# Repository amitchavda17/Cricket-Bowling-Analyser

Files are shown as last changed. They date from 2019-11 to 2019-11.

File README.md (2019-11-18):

# Cricket-Bowling-Analyser

Cricket Bolwing analyser is  a low cost embedded system  that can be used for analysing bolwers perfromance analysis in Cricket.The system is capable of measuring line length and speed of delivery.
The system consist of an  sensor matrix integrated with embedded system for measuring line and length of delivery and uses ultrasonic sensor for measuring the speed of dleivery.
A basic GUI is designed for  providing performance  analysis to user.

## The [Report](https://github.com/amitchavda17/Cricket-Bowling-Analyser/blob/master/Report.pdf) file contians following
* Detail explanation of project with required components and  results  
* Process of designing sensor matrix using velostat with measurments 
* Block diagram for system 
* Schematic Diagram for [PCB](https://github.com/amitchavda17/Cricket-Bowling-Analyser/tree/master/Circuit)
* Circuit diagram for sesnor arduino interfacing

## Code files
* [sensor interfacing](https://github.com/amitchavda17/Cricket-Bowling-Analyser/blob/master/sensor_matrix.ino) this file contains code for data acqusition from sensor matrix and generating results
* [Speed measrument](https://github.com/amitchavda17/Cricket-Bowling-Analyser/blob/master/speed_measurment.ino) code for speed measrument using ultrasonic sensor
* [Live visualization](https://github.com/amitchavda17/Cricket-Bowling-Analyser/blob/master/live_visualization.pde) Processing3 code written in java for visualzing results in real time
* [GUI](https://github.com/amitchavda17/Cricket-Bowling-Analyser/tree/master/GUI) using pyQt in python and webased using html

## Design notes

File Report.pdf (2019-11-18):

# CRICKET BOWLING ANALYSER

I

## ABSTRACT

This project is an alternative for the expensive performance evaluating systems available

in the market today. Individual bowlers will be able to evaluate their performances on their own

with the help of statistics and graphs provided by our system. More specifically, individuals will

be able to keep a check on their consistency as a bowler based on bowling parameters like line,

length, and speed.

In this system, we will be developing a grid of velostat polymer which will be used as a

sensor for the detection of location of ball’s impact on the pitch. This will help us to provide the

line and length of the delivery.

The data collected from this sensor will be accumulated which can be later used to present

to the user using Data Visualization techniques which will make this data intelligible for the user.

The final aim of this project is to provide a performance analyzing and evaluating system

which can be utilized by any layman for the betterment of the sport

II

## TABLE OF CONTENTS

Sr. No. | Page Title | Page No.
1. | Introduction | 1
| 1.1 Introduction of project | 1
| 1.2 Aim and Objective | 4
| 1.3 Scope of the project | 5
2. | Literature Survey | 6
| 2.1 Currently Available Technology | 6
| 2.2 Study Of Sensor | 7
| 2.3 Market Research | 11
3. | Problem Statement | 12
4. | System Development | 13
| 4.1 Block Diagram | 13
| 4.2 Circuit Diagram | 14
| 4.3 PCB Design | 15
| 4.4 Explanation | 16
| 4.5 Working | 16
5. | Hardware Details | 20
| 5.1 Hardware Requirements | 20
6. | Software Details | 24
| 6.1 Software Requirements | 24

III

Sr. No. | Page Title | Page No.
7. | Cost Of Materials | 30
| 7.1 Costing Details | 30
8. | Code Flow Chart | 30
9. | Results | 33
10. | Conclusion & Future Scope | 38
11. | References | 39
12. | Annexure | 40

IV

## LIST OF FIGURES

Fig. no. | Figure | Page no.
1.1 | Cricket pitch | 1
1.2 | Pitch Dimensions | 2
1.3 | Length of Delivery | 3
2.1 | Hawk Eye | 6
2.2 | Pitch Vision | 6
2.3 | Piezoelectric sensor | 7
2.4 | Force sensing resistor | 8
2.5 | Ultrasonic sensor | 9
2.6 | Infrared sensor | 9
2.7 | Velostat | 10
2.8 | Feedback | 11
4.1 | Block Diagram | 13
4.2 | Circuit Diagram | 14
4.3 | Speed Circuit | 14
4.4 | PCB Schematic | 15
4.5 | PCB | 15
4.6 | Implemented Sensor | 17
4.7 | Ultrasonic waves | 18
5.1 | Arduino Nano | 21
5.2 | Arduino Mega | 22
5.3 | Velostat | 22
5.4 | Mux 506 | 23
5.5 | Ultrasonic senor | 23
6.1 | Processing3 | 24
6.2 | Processing 3 display | 25
6.3 | Led and Arduino Interfacing | 26
6.4 | Python | 28

V

Fig. no. | Figure Title | Page no.
9.1 | System Connection | 33
9.2 | Processing3 Visualization | 34
9.3 | CSV file | 35
9.4 | GUI home page | 36
9.5 | GUI second page | 36
9.6 | Line Graph | 37
9.7 | Length Graph | 37

VI

## LIST OF TABLES

Table no. | Content of table | Page no.
2.1 | Technology Comparison | 7
4.1 | Sensor Mat Dimensions | 16
5.1 | Component Specifications | 20
7.1 | Cost of Materials | 30

## CHAPTER 1

## 1. INTRODUCTION

## 1.1 Introduction of project

Cricket is a bat and ball game played between two teams, 11 players each, on a field

which has a rectangular 22-yard-long pitch in the centre. The basic purpose of the game is to

score more runs than your opposing team.

A Cricket match is divided into periods called innings. During the innings, one team

bats while the other fields and vice-versa. All 11 players on the fielding team are on the pitch

at the same time however only two batsmen are the field at any one time.

Cricket fields tend to be oval in shape. The end which is marked off is called the

boundary, with the rectangle “pitch” in the center.

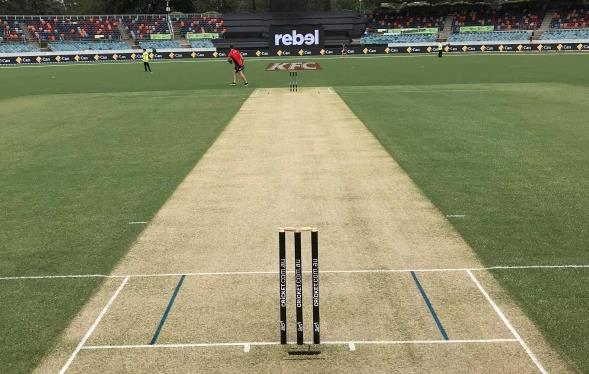
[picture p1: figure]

Fig 1.1 Cricket Pitch

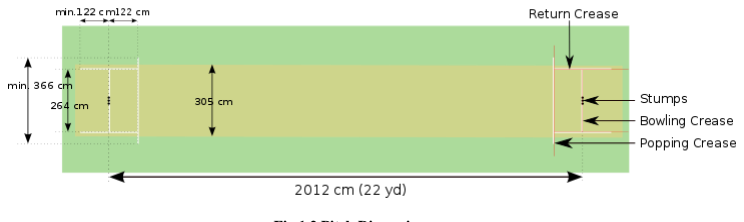
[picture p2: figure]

Fig 1.2 Pitch Dimensions

The essence of the sport is that a bowler delivers (i.e., bowls) the ball from his end of

the pitch towards the batsman who, armed with a bat is "on strike" at the other end.

Bowling, in cricket, is the action of propelling the ball toward the wicket defended by

a batsman. A player skilled at bowling is called a bowler. A single act of bowling the ball

towards the batsman is called a ball or a delivery

The bowler's job is to take as many wickets as possible. That job will be a lot easier if

they have control of their line and length, making the batsman's job of scoring runs that much

more difficult. The line is the direction of the ball in accordance with the batsman's stumps,

while the length is the area of the pitch where the ball bounces.

The length of the ball will determine whether the batsman will play on the front or back foot.

There are five areas the bowler can aim for:

Short length (8 or more meters in front of stumps)

Good length (6 to 8 meters in front of stumps)

Full length (2 to 6 meters in front of stumps)

Yorker(0 to 2 meters in front of stumps)

Different lines that the ball may be said to be traveling on maybe towards off stump,

middle stump or leg stump, outside leg stump, or outside off stump.Line controls how much

room the batsman has to play various shots, and sometimes dictates what shot he must play.

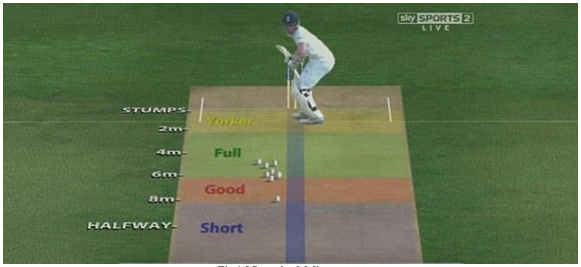
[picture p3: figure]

Fig 1.3 Length of delivery

In the past, cricketers could not see their performance parameters like bowling length, speed

and line; and batting parameters too. If a cricketer was not performing in a match or was lacking

in specific parameter,the fault could not be figured , Like is the bowler injured, less stamina or

learning is wrong, that is bad muscle memory.

With the fast-paced improvement in technology nowadays it is integrated with sports.

Even in cricket there are major changes due to this, like the hawk eye system, sensor bat, led

stumps and stump microphone and camera. In this modern time where we are inclined towards

perfection, we need to work on smart systems that can help sportspeople improve their

gameplay that’s easy for them and are less time consuming.

This Project “Cricket bowling analyser” is a reliable sytem that takes over the task of

evaluating parameters of bowlers in the cricket very accurately and notifies about the

parameters and fault delivery in the bowlers bowling via graphical and statistical data. This

system will consist of VELOSTAT-based pressure mat which will be fabricated in a grid like

structure and laid on the cricket pitch, for speed it will be radar gun. When the bowler’s balls,

the ball will fall on a square part of grid which will give the perfect spot on pitch and once it

hits stump mat, the deviation from the original landing spot and final spot will give the line.

This system can also be enhanced by providing video processing through cameras which

can be recorded and viewed later on. The cricket bowling analyser is a simple sytem that can

turn out to be very helpful for the kids as well as adults who want to learn bowling without

external assistance or in absence of coach

## 1.2 Aim and Objective of project

1. To provide a technology driven aid in the field of cricket that can help budding

cricketers to enhance their performance.

2. Tracking statistics of players with a modern digital approach.
3. Provide a low cost easy to use alternative

## 1.3 Scope of the Project

1. To provide a technologically driven aid that will help in monitoring bowling

performance by measuring line, length and speed of a delivery.

2. A low-cost system that will give necessary features of high cost professional system

that are not easily affordable.

3. This Application will help a weaker section of society to portray their skills.
4. The main target audience of this project are school academies and small clubs

(gymkhanas).

5. This can also be used by individual to target a particular spot to improve bowling and

analyse himself.

## CHAPTER 2

## 2. Literature Survey

## 2.1 Currently available Technology:

### 2.1.1 Hawk eye:

Hawk-Eye is a computer system used in numerous sports such as cricket, tennis,

Gaelic football and volleyball, to visually track the trajectory of the ball and display a

profile of its statistically most likely path as a moving image

Cost- 1.2 crores INR

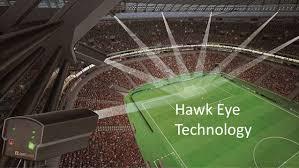
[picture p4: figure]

Fig2.1 Hawk Eye

### 2.1.2 Pitch Vision:

Pitch vision is an innovative cricket training platform that facilitates an analytical

system consisting of motion tracking and video analysis

Cost- 3 -10 Lakhs INR

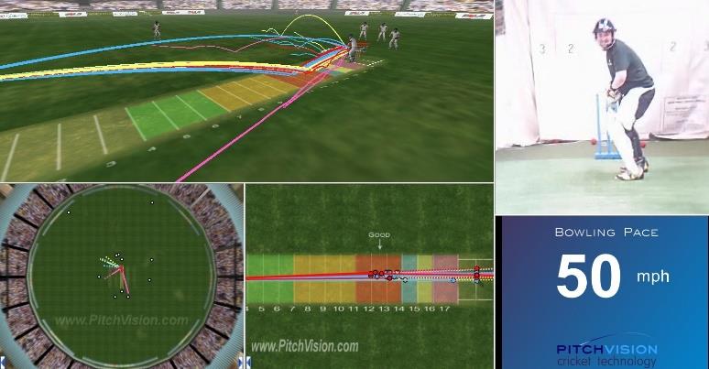
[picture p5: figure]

Fig 2.2 Pitch Vision

Table 2.1 Technology Comparison

The currently available systems considered for cricket, work on the principle of

Image processing and require expensive hardware, and very high processing power and

storage. Hence, we have designed a less expensive embedded system which requires less

processing power and storage.

The main requirement of the embedded system is to collect data on line, length and speed for this purpose we have studied various sensors which can be used to perform the desired task.

## 2.2 Study of Sensor:

### 2.2.1 Piezoelectric sensor:

A piezoelectric sensor is a device that uses the piezoelectric effect, (https://en.wikipedia.org/wiki/Piezoelectric_effect) to measure changes

in pressure, (https://en.wikipedia.org/wiki/Pressure) acceleration, (https://en.wikipedia.org/wiki/Acceleration) temperature, (https://en.wikipedia.org/wiki/Temperature) strain, (https://en.wikipedia.org/wiki/Strain_(materials_science)) or force (https://en.wikipedia.org/wiki/Force) by converting them to an electrical

charge. (https://en.wikipedia.org/wiki/Electrical_charge) Piezoelectric sensors are versatile tools for the measurement of various processes. They

are used for quality assurance, (https://en.wikipedia.org/wiki/Quality_assurance) process control, (https://en.wikipedia.org/wiki/Process_control) for research and development in many

industries.

SYSTEM | TECHNOLOGY | HARDWARE | APPLICATION | COST (INR)
HAWK EYE | IMAGE PROCESSING | HIGH END CAMERA | MATCH | 2.5CR
PITCH VISION | EMBEDDED SYSTEM & IMAGE PROCESSING | CAMERA, SENSOR MAT | MATCH & TRAINING | 3LAKHS
CRICKET BOWLING ANALYZER | EMBEDDED SYSTEM | SENSOR MAT | TRAINING | 30K

Usability-Piezoelectric sensor are inexpensive pressure sensors but the output of these

sensor is not stable so they are not suited for measurement of line and length of delivery as they

fail to detect impact of ball and also they are easily prone to damage by high impact.

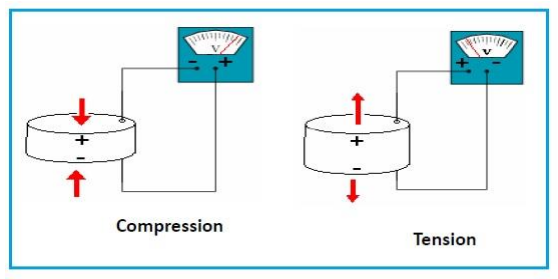
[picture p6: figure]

Fig 2.3 piezoelectric sensor

### 2.2.2 Force sensing resistor:

Force-sensing resistors consist of a conductive polymer, (https://en.wikipedia.org/wiki/Conductive_polymer) which changes resistance in a

predictable manner following application of force to its surface. They are normally supplied as

a polymer sheet or that can be applied by screen-printing. (https://en.wikipedia.org/wiki/Screen_printing) The sensing film consists of both

electrically conducting and non-conducting particles suspended in matrix. The particles are

sub-micrometer sizes, and are formulated to reduce the temperature dependence, improve

mechanical properties and increase surface durability.

Usability-These are expensive sensors which are excellent for detection of impact but

it is practically difficult and expensive to design a pressure sensing grid using these sensors.

Fig2.4 Force sensing resistor

### 2.2.3 Ultra sonic sensor:

Ultrasonic sensors are a type of acoustic sensor divided into three broad categories:

transmitters, receivers and transceivers. Transmitters convert electrical signals (https://en.wikipedia.org/wiki/Signal_(electrical_engineering)) into ultrasound, (https://en.wikipedia.org/wiki/Ultrasound)

receivers convert ultrasound into electrical signals, and transceivers can both transmit and

receive ultrasound.

Usability- Work on ultrasound and have a field of 120 degree so they are used for

measurement of speed of delivery

Fig 2.5 Ultrasonic sensor

### 2.2.4 IR sensor:

An infrared sensor is an electronic device that emits in order to sense some aspects of

the surroundings. An IR sensor can measure the heat of an object as well as detects the motion.

These types of sensors measures only infrared radiation, rather than emitting it that is called as

a passive IR sensor.

Usability-Due to low range of operation they are not advisable for use.

Fig 2.6 IR sensor

### 2.2.5 Velostat

Velostat is a piezoresistive material, meaning it’s electrical resistance decreases when

pressured. When sandwiched between two conductive layers, it has a wonderful range for

making pressure and bend sensors. It can also be used for resistive sensing over distance,

position sensing. Velostat is a back, opaque, volume-conductive, carbon-impregnated

polyolefin. The electrical characteristics are not affected by age or humidity (but they do

change when melted under the iron).

Usability-This is well suited for design of pressure sensor as per the requirement of the

project. This polymer is soft, flexible, light, thin and can handle heavy impacts.

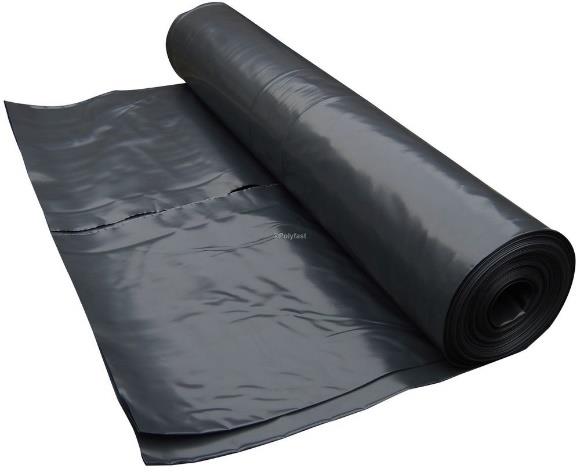
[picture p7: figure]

Fig 2.7 Velostat polymer

## 2.3 Market Research:

During the process of system designing we met with a few cricket clubs and explained

them our system idea to get their feedback and suggestion on practical application of the

proposed system.

We visited PTVA Sports Acadmey,Vile Parle,Mumbai to get a feedback on our

idea .We met with their head coach Mr.Suren D.Ayre

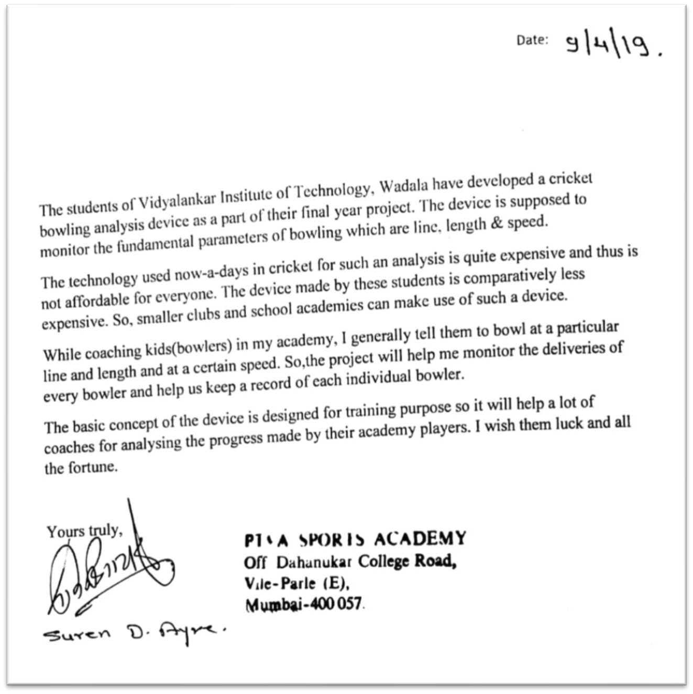
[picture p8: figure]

Fig 2.8 Feedback

## CHAPTER 3

## 3. Problem Statement

To provide a cheaper alternative for the expensive systems available for cricket

bowling performance analysis and help individual bowlers to evaluate their own consistency

and progress.

## CHAPTER 4

## 4. System Development

## 4.1 Block Diagram

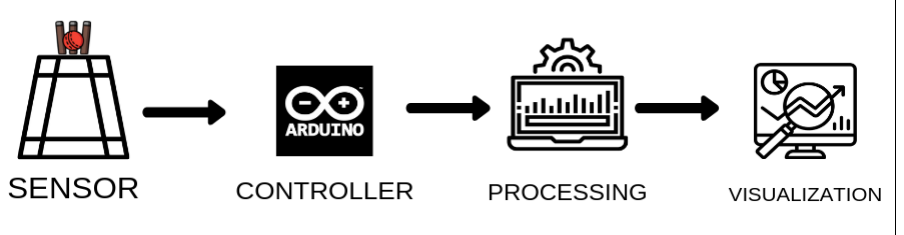
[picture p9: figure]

Fig 4.1 Block Diagram

The main goal of the system is to monitor and analyze cricket bowling parameters

viz. line, length and speed which are the essential parameters of the multi-faceted sport for any

budding cricketer. This will help the player to access and improve upon his/her bowling

engendering higher performances. Due to this system, the fundamentals of any cricket bowler

will be tested and polished.

An embedded system is designed that uses pressure sensors developed using velostat

to detect the location of ball impact, which is then interfaced with the controller, and the

acquired data is processed appropriately and is used to give proper information about the line,

length, and length of the delivery.

This processed data will be stored in the storage device and specific directory will

be maintained for every user for all the overs bowled and this data can be processed using data

visualization techniques and can be represented in the form of graphs and chart which provide

a summary of the performance and help in better understanding the data instead of mere table

or spread sheets. Data can be stored for a longer duration which will help in tracking a

performance for a period which gives all the insights in the various trends that has taken place

during this period.

## 4.2 Circuit Diagram:

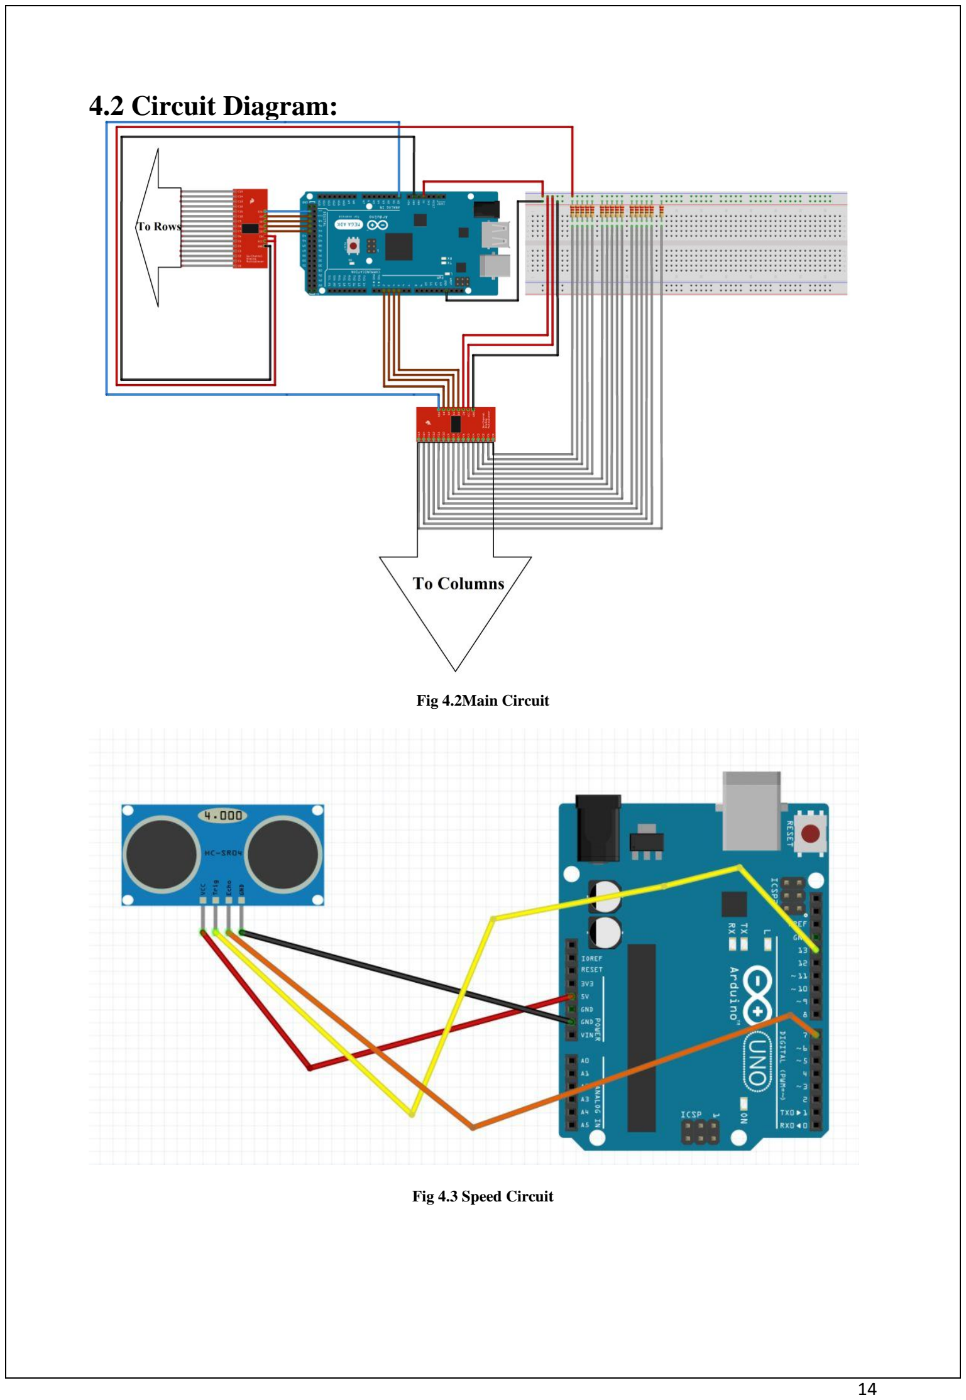
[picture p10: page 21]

Fig 4.2Main Circuit

Fig 4.3 Speed Circuit

## 4.3 PCB

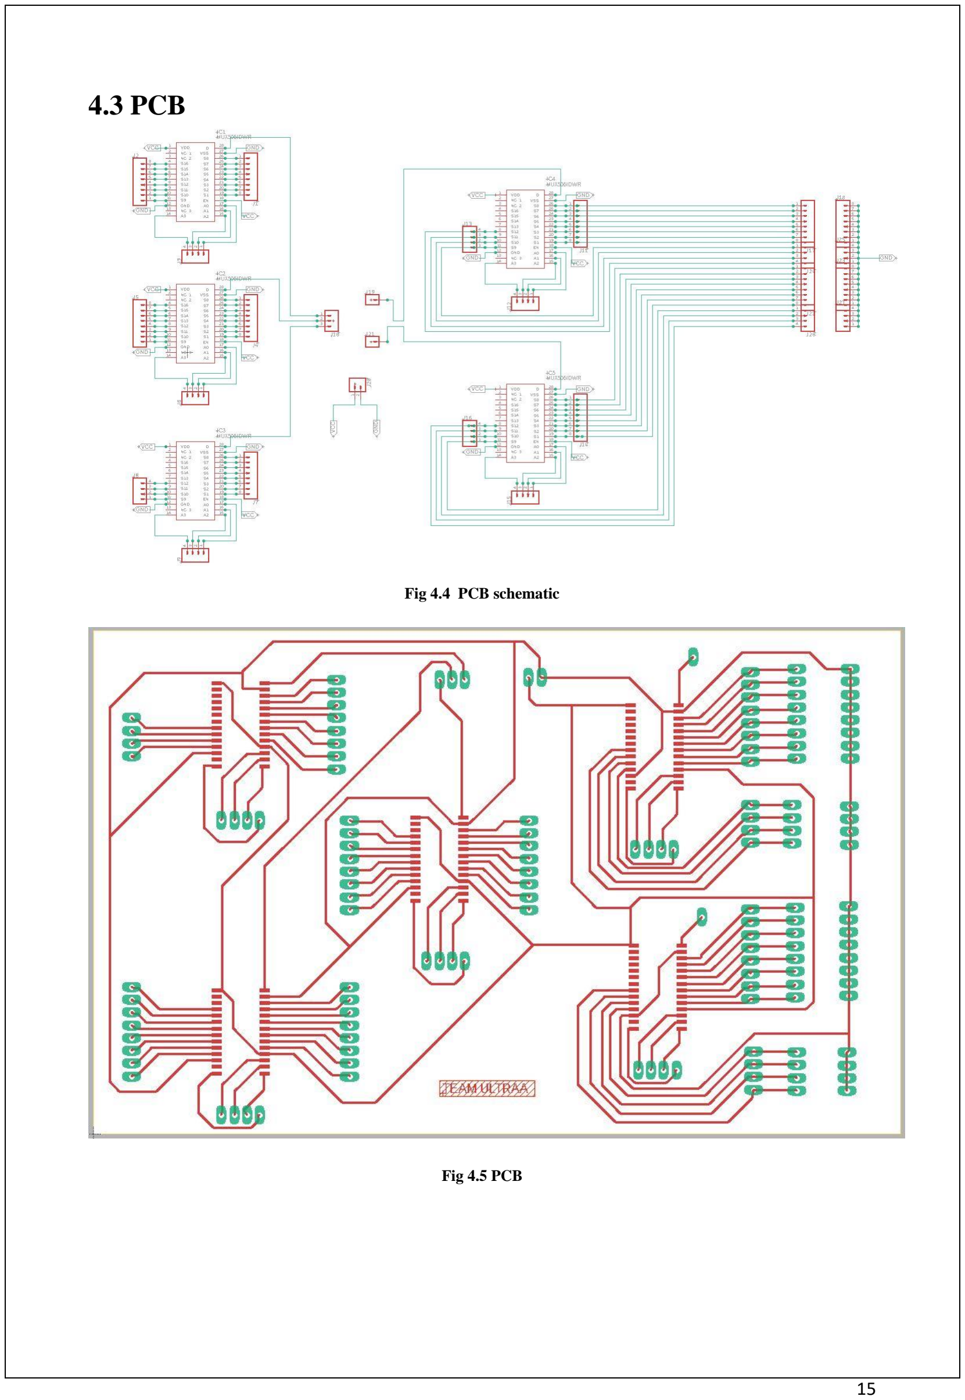
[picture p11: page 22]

Fig 4.4 PCB schematic

Fig 4.5 PCB

## 4.4 Explanation:

The circuit is designed for measuring line and length of ball delivery, it consists of 2

pair of 16:1 mux interfaced with Arduino. One pair of mux is interfaced with Pitch pressure

sensing matrix for measuring length of delivery and another pair is connected with back screen

matrix for measuring line of delivery.

The 16 channels of 1 mux are connected to rows of matrix and the 16 channels of other

mux are connected to columns of same matrix. Select pins of multiplexers are connected to

Arduino, switching of multiplexer channels is done via Arduino.

A voltage divider section is created on the output side and the output of this section is

fed to 16 channels of second mux then this Output is given to analog pin of Arduino.

An ultrasonic sensor is interfaced with Arduino for measuring the speed of delivery and

the speed data is also fed to csv file.

## 4.5 Working:

The primary task of the system is to measure line, length, speed of delivery. For

measurement different sensors are interfaced with microcontroller to acquire the data.

### 4.5.1 Pressure sensing mat:

BIG MAT
COPPER STRIP | | LENGTH (cm) | BREADTH (cm) | NO OF STRIPS
| ROW | 75 | 3.5 | 30
| COLUMN | 180 | 3.5 | 12
VELOSTAT | LENGTH (cm) | BREADTH (cm)
| 180 | 75

SMALL MAT
COPPER STRIP | | LENGTH (cm) | BREADTH (cm) | NO OF STRIPS
| ROW | 75 | 3.5 | 12
| COLUMN | 75 | 3.5 | 12
VELOSTAT | LENGTH (cm) | BREADTH (cm)
| 75 | 75

Table 4.1 Senor mat dimensions

Pressure sensing mat is designed using velostat polymer. The aim of this sensor is to

give the exact location at which pressure is applied. Matrix structure of the mat is helpful in

finding the location of pressure change. The sensor will return 2D coordinates of the location

of pressure change. A number of copper strips are used as rows and columns and the velostat

polymer is sandwiched between the copper strips to create the pressure sensing matrix. The

mat used in the system consists of a matrix structure with 30 rows and 12 columns. The data

given by this matrix is used to track the length of delivery. Another matrix of 12 rows and 9

columns is used to measure the line of the delivery. The 30 rows X 12 columns mat used for

determining the length of the delivery is placed on the pitch and the 12 rows X 9 columns mat

is placed behind the stumps on a vertically oriented screen, which helps in determining the line

of delivery.

The matrix structure is interfaced with the microcontroller using analog multiplexer

mux506. The multiplexers are used to control the input and output of the matrix. The rows and

columns of the matrix are connected to the channels of separate set of multiplexers responsible

for controlling rows and columns independently. The row section of the matrix is used as input

and the columns are used to measure the output.

The operation of pressure sensing matrix is dependent on change in impedance of the

polymer, according to the ohm’s law voltage is directly proportional to impedance, using this

law the voltage change at the location of ball’s impact is monitored using the mux.

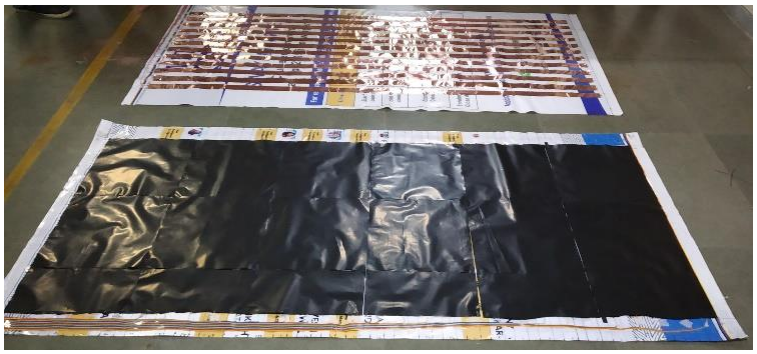
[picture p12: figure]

Fig 4.6 Implemented Sensor

The microcontroller sends a 5V input signal to the multiplexers,which are controls, the

switching of rows. The signal is transferred to one channel at a time and the columns are

continuously monitored for detecting any major surge in voltage. This voltage surge from the

multiplexers is fed into the microcontroller.

The system takes approximately 64 ms to scan both the mats with Arduino Mega 2560 (16

MHz crystals). After removing the pre-scaler, the scanning time is reduced to 11 ms. This

helps us to detect the impact of the ball.

### 4.5.2 Ultrasonic speed gun:

The speed gun is used for measuring the speed of delivery and it is designed using

ultrasonic sensor. Ultrasonic sensors measure distance by using ultrasonic waves. The sensor

head emits an ultrasonic wave and receives the wave reflected back from the target. Ultrasonic

Sensors measure the distance to the target by measuring the time between the emission and

reception.

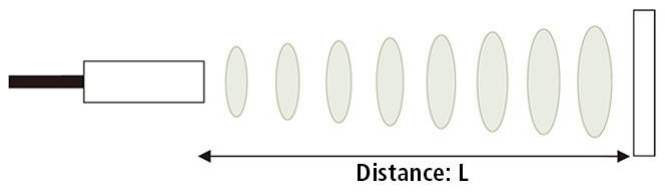
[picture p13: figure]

Fig 4.7 ultrasonic waves

An ultrasonic sensor uses a single ultrasonic element for both emission and reception.

In a reflective model ultrasonic sensor, a single oscillator emits and receives ultrasonic waves

alternately. This enables miniaturization of the sensor head.

Ultrasonic sensor module comprises of one transmitter and one receiver. The

transmitter can deliver 40 KHz ultrasonic sound while the maximum receiver is designed to

accept only 40 KHz sound waves. The receiver ultrasonic sensor that is kept next to the

transmitter shall thus be able to receive reflected 40 KHz, once the module faces any obstacle

in front. Thus, whenever any obstacles come ahead of the ultrasonic module it calculates the

time taken from sending the signals to receiving them since time and distance are related for

sound waves passing through air medium at 343.2m/sec.

### Distance calculation:

The distance can be calculated with the following formula:

Distance L = 1/2 × T × C

where L is the distance, T is the time between the emission and reception, and C is the sonic

speed. (The value is multiplied by 1/2 because T is the time for go-and-return distance.)

### Speed measurement:

The ultrasonic sensor is placed on the stumps facing towards the bowler. The sensor

continuously emits ultrasound, when the ball is bowled the sensor detects the ball twice, one at

distance d1 and one more time at distance d2. So, only two waves reflected back at the distances

d1 and d2 are considered. This enables us to determine the time between the two distances and

hence the speed of the delivery.

### 4.5.3 Data Acquisition and Visualization:

The data collected from sensor matrix is fed to Arduino where processing of the data

takes places. Further, the processed data is then sent serially to Processing 3 software which is

used to format the data and load in CSV file. At the same time the formatted data is visualized

in real time. CSV files are used to store the data on line, length and speed of delivery. This

accumulated data is used for long-term analysis of trends in performance. The data from CSV

files is loaded in python and analyzed using graphs to show the tabular data in simple form.

Finally, a GUI is developed to give user a smooth access to this data.

## CHAPTER 5

## 5. HARDWARE DETAILS

## 5.1Hardware Requirments:

SR NO | COMPONENTS | SPECIFICATION
1 | Arduino Nano | ATmega328P,16MHz
2 | Arduino Mega | ATmega 2560 AU
3 | Velostat polymer | 50,000 ohm/sq metre
4 | MUX 506 | 16:1 Analog Mux
5 | Ultrasonic Sensor | Detection range: 2cm – 1000cm
6 | Copper Stripes | Conductivity: 5.96 x 10⁷ S/m

Table 5.1: Component Specifications
5.1.1Arduino Nano:

Arduino Nano is an open source platform for programming. The Arduino Nano is a

small, complete, and breadboard-friendly board based on the Atmega328P.It has 22

digital input/output pins (of which 6 can be used as PWM outputs), 8 analog inputs, a 16 MHz

ceramic resonator, a USB connection, an ICSP header, and automatic reset.

It contains everything needed to support the microcontroller; simply connect it to a

computer with a USB cable or power it with a AC-to-DC adapter or battery to get started. The

Arduino Nano has many facilities for communicating with a computer, another

Arduino, or other microcontrollers. The Atmega328P provide UART TTL (5V) serial

communication, which is available on digital pins 0 (RX) and 1 (TX). The Arduino

Nano can be programmed with the Arduino software (download). (http://www.arduino.org/software) The Atmega328P

on the Arduino Nano comes preburnt with a boot loader that allows you to upload

new code to it without the use of an external hardware programmer.

Fig 5.1 Arduino Nano

### 5.1.2 Arduino Mega:

Arduino is an open-source physical computing platform based on a simple i/o board

and a development environment that implements the Processing/Wiring language. Arduino can

be used to develop stand-alone interactive objects or can be connected to software on your

computer (e.g. Flash, Processing, MaxMSP). The open-source IDE can be downloaded for free

(currently for Mac OS X, Windows, and Linux).

The Arduino Mega is a microcontroller board based on the ATmega2560. It has 54

digital input/output pins (of which 14 can be used as PWM outputs), 16 analog inputs, 4 UARTs

(hardware serial ports), a 16 MHz crystal oscillator, a USB connection, a power jack, an ICSP

header, and a reset button. It contains everything needed to support the microcontroller; simply

connect it to a computer with a USB cable or power it with a AC-to-DC adapter or battery to

get started. Never fear for accidental electrical discharge, either since since the Mega also

includes a plastic base plate to protect it!

The Mega 2560 R3 also adds SDA and SCL pins next to the AREF. In addition, there

are two new pins placed near the RESET pin. One is the IOREF that allow the shields to adapt

to the voltage provided from the board. The other is a not connected and is reserved for future

purposes. The Mega 2560 R3 works with all existing shields but can adapt to new shields which

use these additional pins.

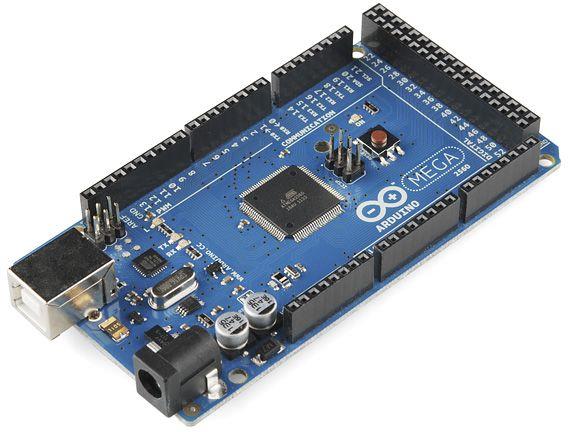
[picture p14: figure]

Fig 5.2 Arduino Mega

### 5.1.3 Velostat Polymer:

Velostat (50000-ohm, 4 mil), which is produced by 3M and consists of a polymeric foil

(11µm thickness) impregnated with carbon black. For the electrodes, we use a copper sheet

strip (40 microns), which is also commonly available. The outer protection layer is made of a

plastic flex.

Due to its properties of changing its resistance with either flexing or pressure it is

becoming popular with hobbyists for making inexpensive sensors for microcontroller

experiments. One example of this is to make shoes which light up when the wearer takes a step.

Since the resistance (https://en.wikipedia.org/wiki/Electrical_resistance) in the circuit is reduced when pressure is applied, this reading can indicate

when weight is applied or removed from the shoes.

Fig 5.3 Velostat

### 5.1.4 Texas Instrument Mux506:

The MUX506 and MUX507 (MUX50x) are modern complementary metal-oxide

semiconductor (CMOS) precision analog multiplexers (muxes). The MUX506 offers 16:1

single-ended channels, whereas the MUX507 offers differential 8:1 or dual 8:1 single-ended

channels. The MUX506 and MUX507 work equally well with either dual supplies (±5 V to

±18 V) or a single supply (10 V to 36 V). These devices also perform well with symmetric

supplies (such as VDD = 12 V, VSS = –12 V), and unsymmetric supplies (such as VDD = 12

V, VSS = –5 V). All digital inputs have transistor-transistor logic (TTL) compatible thresholds,

providing both TTL and CMOS logic compatibility when operating in the valid supply voltage

range.

Fig 5.4 Mux506

### 5.1.6 Ultrasonic Sesnor:

Ultrasonic sensor module comprises of one transmitter and one receiver. The

transmitter can deliver 40 KHz ultrasonic sound while the maximum receiver is designed to

accept only 40 KHz sound waves. The receiver ultrasonic sensor that is kept next to the

transmitter shall thus be able to receive reflected 40 KHz, once the module faces any obstacle

in front. Thus, whenever any obstacles come ahead of the ultrasonic module it calculates the

time taken from sending the signals to receiving them since time and distance are related for

sound waves passing through air medium at 343.2m/sec.

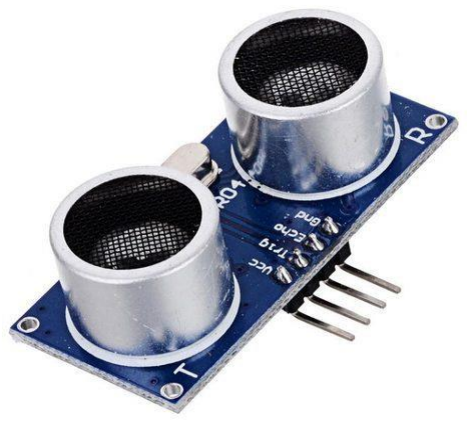
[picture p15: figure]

Fig 5.5 Ultrasonic Sensor

## CHAPTER 6

## 6. SOFTWARE DETAILS

## 6.1 Software Requirements:

### 6.1.1 Processing3:

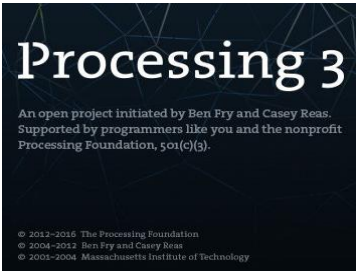
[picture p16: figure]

Fig 6.1 Processing 3

Processing is an open-source graphical library and integrated development environment

(IDE) / playground built for the electronic arts, new media art, and visual design communities

with the purpose of teaching non-programmers the fundamentals of computer programming in

a visual context.

Processing uses the Java language, with additional simplifications such as additional

classes and aliased mathematical functions and operations. As well as this, it also has a

graphical user interface for simplifying the compilation and execution stage.

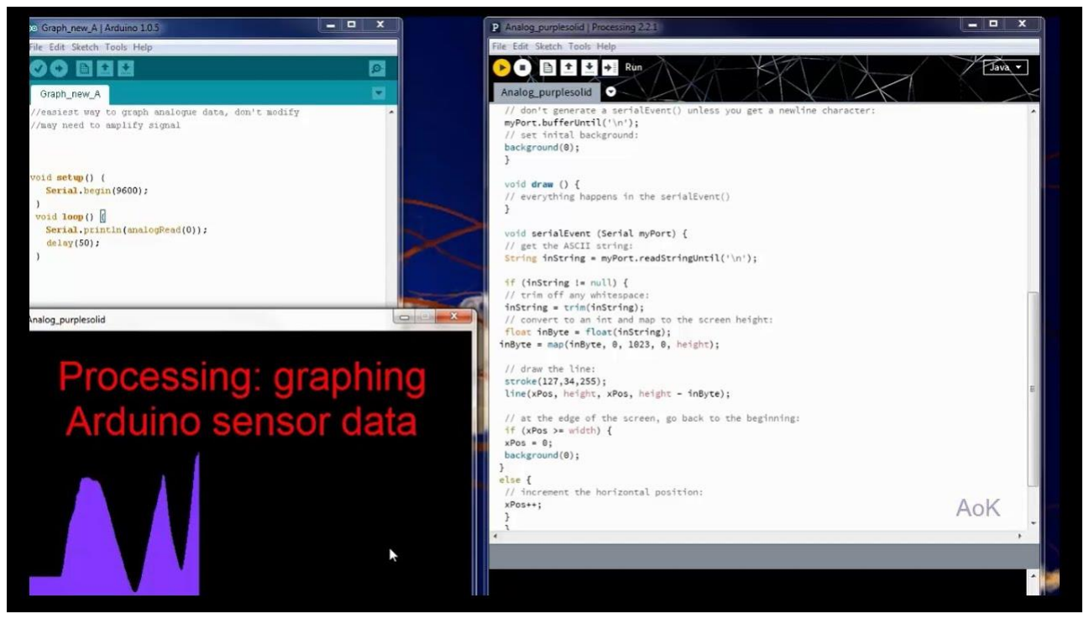
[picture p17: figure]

Fig 6.2 Processing 3 display

Interfacing Arduino with Processing3 using a simple example of turning a LED ON & OFF

Arduino Circuit

The connections for this tutorial are very easy. Connect the two end pins of the 1k

potentiometer to the 5V and the GND pin of the Arduino. Then connect the middle pin of the

potentiometer to the A0 on Arduino. Then connect the positive pin of the LED to pin 7 on the

Arduino and the negative pin of the LED to the GND pin through the 220 ohm resistor.

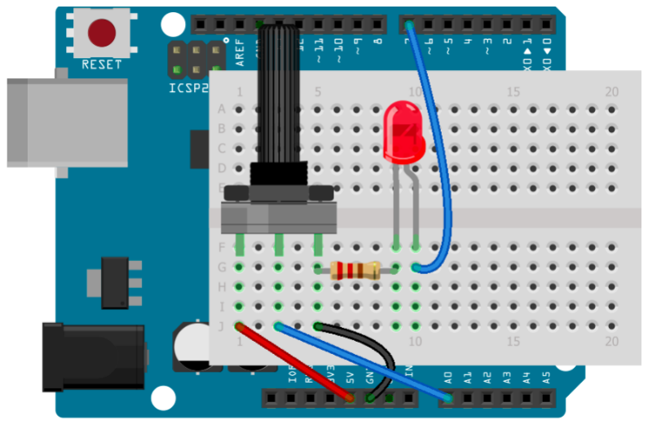
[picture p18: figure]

Fig 6.3 Led Arduino interfacing

Working

The Arduino IDE and the Processing IDE will communicate with each other through

serial communication. The Processing IDE has a serial library which makes it easy to

communicate with the Arduino.

When we move the potentiometer knob, the Arduino will send a value between 0 and

255 to the Processing IDE. The Processing IDE will then change the color of the serial window

according to the movement of the potentiometer knob.

Similarly, when we press the mouse button in the serial window of the Processing IDE,

the Processing IDE will send a ‘1’ or ‘0’ depending on the left or right mouse button to the

Arduino IDE. The Arduino IDE will then turn the LED ON or OFF according to the button

pressed.

Arduino Code

int led_pin = 7; // Initializing the LED pin
int pot_pin = A0; // Initializing the Potentiometer pin
int pot_output; // Declaring a variable for potentiometer output
void setup ( ) {
pinMode(led_pin, OUTPUT); // Declaring the LED pin as output pin Serial.begin(9600); // Starting the serial communication at 9600 baud rate }
void loop ( ) {
pot_output = analogRead (pot_pin); // Reading from the potentiometer
int mapped_output = map (pot_output, 0, 1023, 0, 255); // Mapping the output of potentiometer to 0-255 to be read by the Processing IDE
Serial.println (mapped_output); // Sending the output to Processing IDE

if (Serial.available ( ) > 0) { // Checking if the Processing IDE has send a value or not char state = Serial.read ( ); // Reading the data received and saving in the state variable
if(state == '1') | // If received data is '1', then turn on LED\
{
digitalWrite (led_pin, HIGH);
}
if (state == '0') { // If received data is '0', then turn off led digitalWrite (led_pin, LOW);
}
}
delay(50);
}

Processing

The Processing IDE will accept the data from the Arduino IDE through the Serial

communication and will change the color of the serial window according to the data. It will

also send ‘1’ or ‘0’ depending on the mouse button pressed. The Processing IDE has a serial

library which makes it able to communicate with the Arduino IDE.

import processing.serial.*; // Importing the serial library to communicate with the Arduino Serial myPort; // Initializing a vairable named 'myPort' for serial communication
float background_color ; // Variable for changing the background color
void setup ( ) {
size (500, 500); // Size of the serial window, you can increase or decrease as you want
myPort = new Serial (this, "COM3", 9600); // Set the com port and the baud rate according to the Arduino IDE
myPort.bufferUntil ( '\n' ); // Receiving the data from the Arduino IDE
}
void serialEvent (Serial myPort) {
background_color = float (myPort.readStringUntil ( '\n' ) ) ; // Changing the background color according to received data
}
void draw ( ) {

background ( 150, 50, background_color ); // Initial background color, when we will open the serial window

if ( mousePressed && ( mouseButton == LEFT ) ) { // if the left mouse button is pressed

myPort.write ( '1' ) ; // send a '1' to the Arduino IDE

}

if ( mousePressed && ( mouseButton == RIGHT ) ) { // if the right mouse button is pressed

myPort.write ( '0' ) ; // Send a '0' to the Arduino IDE

### 6.1.2 Python 3:

Python is an interpreted, (https://en.wikipedia.org/wiki/Interpreted_language) high-level, (https://en.wikipedia.org/wiki/High-level_programming_language) general-purpose (https://en.wikipedia.org/wiki/General-purpose_programming_language) programming language. (https://en.wikipedia.org/wiki/Programming_language) Created

by Guido van Rossum (https://en.wikipedia.org/wiki/Guido_van_Rossum) and first released in 1991, Python has a design philosophy that

emphasizes code readability, (https://en.wikipedia.org/wiki/Code_readability) notably using significant whitespace. (https://en.wikipedia.org/wiki/Significant_whitespace) It provides constructs that

enable clear programming on both small and large scales.

Python is dynamically typed (https://en.wikipedia.org/wiki/Dynamic_programming_language) and garbage-collected. (https://en.wikipedia.org/wiki/Garbage_collection_(computer_science)) It supports multiple programming

paradigms, (https://en.wikipedia.org/wiki/Programming_paradigm) including procedural, (https://en.wikipedia.org/wiki/Procedural_programming) object-oriented, (https://en.wikipedia.org/wiki/Object-oriented_programming) and functional programming. (https://en.wikipedia.org/wiki/Functional_programming) Python

features a comprehensive standard library, (https://en.wikipedia.org/wiki/Standard_library) and is referred to as "batteries included".

Python interpreters are available for many operating systems. (https://en.wikipedia.org/wiki/Operating_system) CPython, (https://en.wikipedia.org/wiki/CPython) the reference

implementation (https://en.wikipedia.org/wiki/Reference_implementation) of Python, is open-source software (https://en.wikipedia.org/wiki/Open-source_software) and has a community-based development

model. Python and CPython are managed by the non-profit Python Software Foundation. (https://en.wikipedia.org/wiki/Python_Software_Foundation)

### 6.4 Python

### 6.1.3 PyQt:

PyQt is one of the most popular Python bindings for the Qt cross-platform C++

framework. PyQt developed by Riverbank Computing Limited. Qt itself is developed as part

of the Qt Project. PyQt provides bindings for Qt 4 and Qt 5. PyQt is distributed under a choice

of licences: GPL version 3 or a commercial license.

PyQt is available in two editions: PyQt4 which will build against Qt 4.x and 5.x and

PyQt5 which will only build against 5.x. Both editions can be built for Python 2 and 3. PyQt contains over 620 classes that cover graphical user interfaces, XML handling, network

communication, SQL databases, Web browsing and other technologies available in Qt.

The latest iteration of PyQt is v5.11.3. It fully supports Qt 5.11.2.

PyQt4 runs on Windows, Linux, Mac OS X and various UNIX platforms. PyQt5 also

runs on Android and iOS.

### 6.1.4 Matplotlib:

Matplotlib is a Python 2D plotting library which produces publication quality figures

in a variety of hard copy formats and interactive environments across platforms. Matplotlib can

be used in Python scripts, the Python and IPython shells, the Jupyter notebook, web application

servers, and four graphical user interface toolkits.

Matplotlib tries to make easy things easy and hard things possible. You can generate

plots, histograms, power spectra, bar charts, error charts, scatterplots, etc., with just a few lines

of code. For examples, see the sample plots and thumbnail gallery.

For simple plotting the pyplot module provides a MATLAB-like interface, particularly

when combined with IPython. For the power user, you have full control of line styles, font

properties, axes properties, etc, via an object-oriented interface or via a set of functions familiar

to MATLAB users.

## CHAPTER 7

## 7. Cost of Materials

## 7.1 Costing Details:

Sr no | Name | Quantity | Cost(INR)
1 | Velostat | 1.8 sq.meter | 11000
2 | Arduino Mega | 1 | 800
3 | Mux506 | 4 | 400
4 | Aruino Nano | 1 | 500
5 | PCB | 1 | 1000
6 | Ultrasonic sensor | 1 | 100
8 | Copper sheet | 30 sq feet | 1800
9 Wires ,cables and | accessories | | 6000
Total | | | 21,500

Table 7.1 Cost of Materials

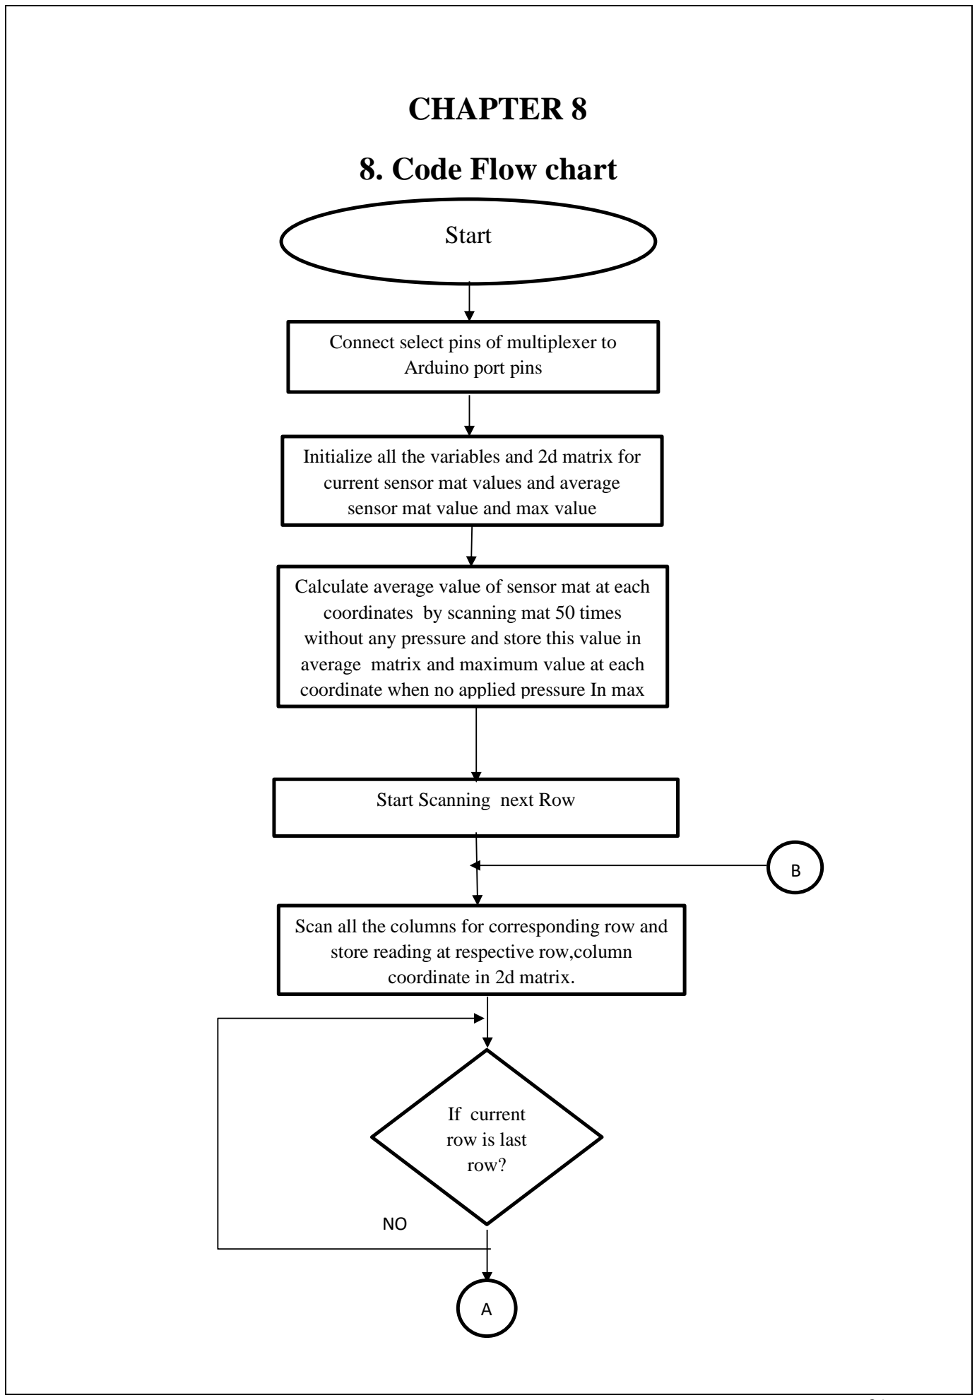
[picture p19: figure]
CHAPTER 8; 8. Code Flow chart; Start; Connect select pins of multiplexer to Arduino port pins; current sensor mat values and average sensor mat value and max value; coordinates by scanning mat 50 times; Start Scanning next Row; store reading at respective row,column coordinate in 2d matrix.; If current row is last row?

Initialize all the variables and 2d matrix for

Calculate average value of sensor mat at each

without any pressure and store this value in average matrix and maximum value at each coordinate when no applied pressure In max

Scan all the columns for corresponding row and

Using the current matrix reading stored in 2D mat matrix and average stored in avg matrix

coordinate and return the coordinate with

Repeat the same process for back screen matrix

## CHAPTER 9 9. Results

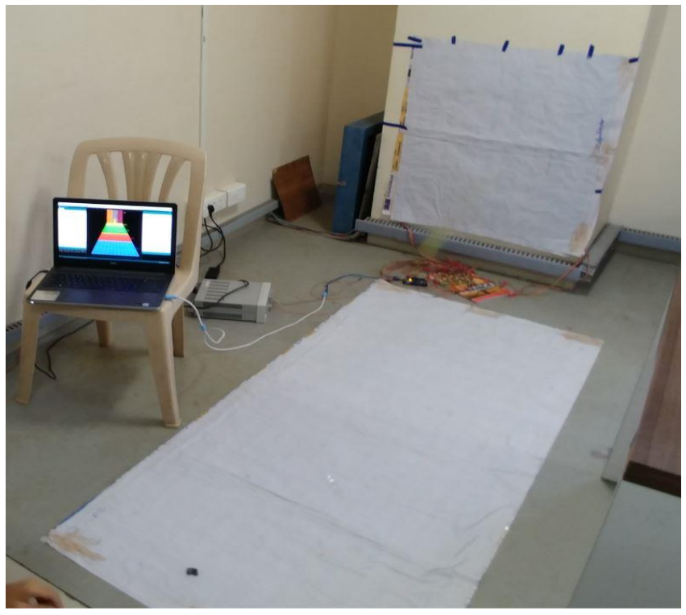
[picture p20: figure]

Fig 9.1 System Connection

This is how the setup looks like when the whole system is assembled. The larger mat is

overlaid on the ground (which gives the length) and the smaller mat is held behind (which gives

the line).

On an average the ball takes approximately 11 ms to bounce off the pitch. Our system

can detect whether the ball has bounced on the pitch if the bounce time in 11 ms. That is, the

arduino scans the enter mat (both mats) in 11 ms.

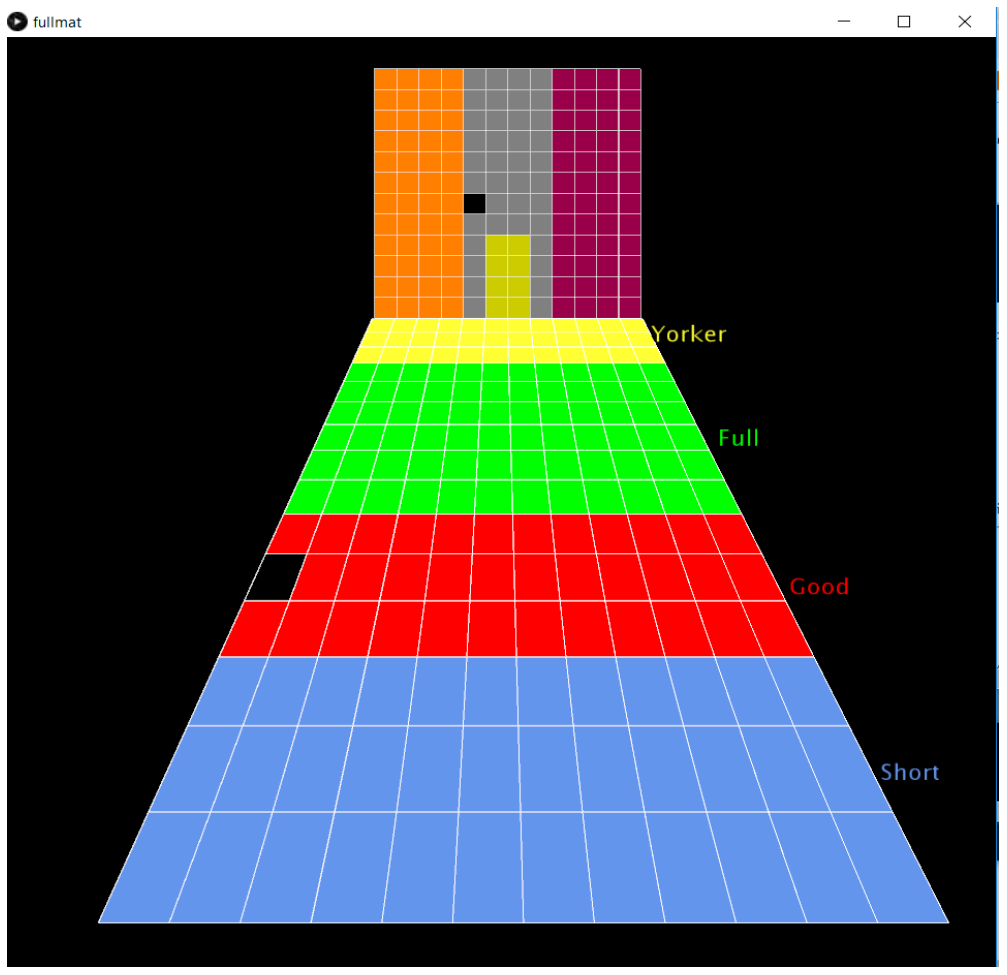
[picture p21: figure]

Fig 9.2 Processing3 visualization

This is virtual representation of the real setup developed using processing3.It shows

live visualization of the real time delivery.The bottom pitch is divided into 4 section which

shows the length of delivery viz. Yorker,full,good,short.The back screen is divided into 3

section which shows line of delivery viz. off,middle,leg.

The black box visible on the screen shows the exact coordinates of the delivery and the

colour code helps in deciphering the length and line of delivery.processing3 also collects the

data from Arduino and loads the data into csv file.

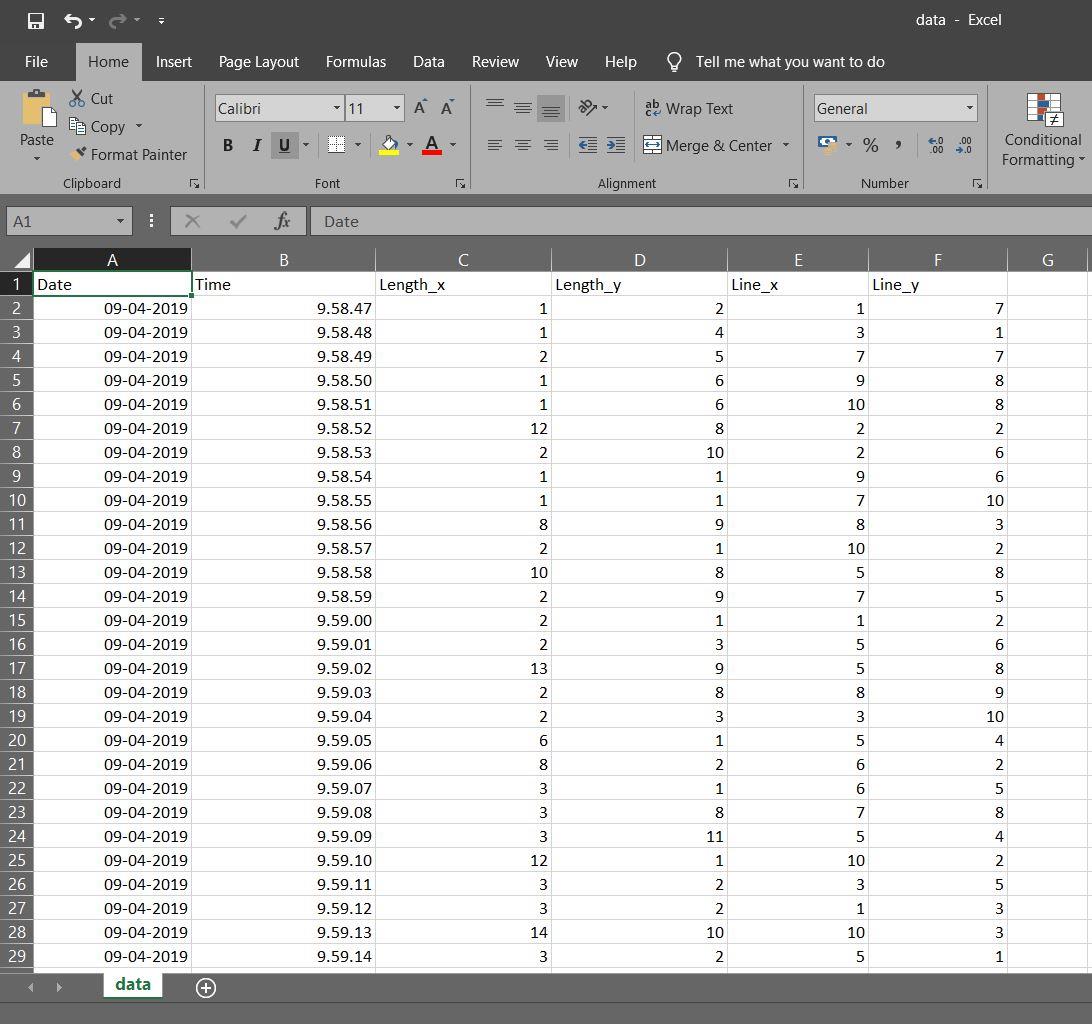
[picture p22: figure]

Fig 9.3 CSV File

The above figure shows the format in which data is stored in csv files. The line and

length data from the processing software is stored along with date and time instantaneously,

when it was acquired. This csv file helps in long term storage of data and this data can be

retrieved later for further graphical analysis.length_x and length_y represents the x,y

coordinate of lengthparticular delivery similarly line_x and line_y gives the x,y coordinate for

line. Date-time stamp is added for aiding the processing of data for generating graphs.

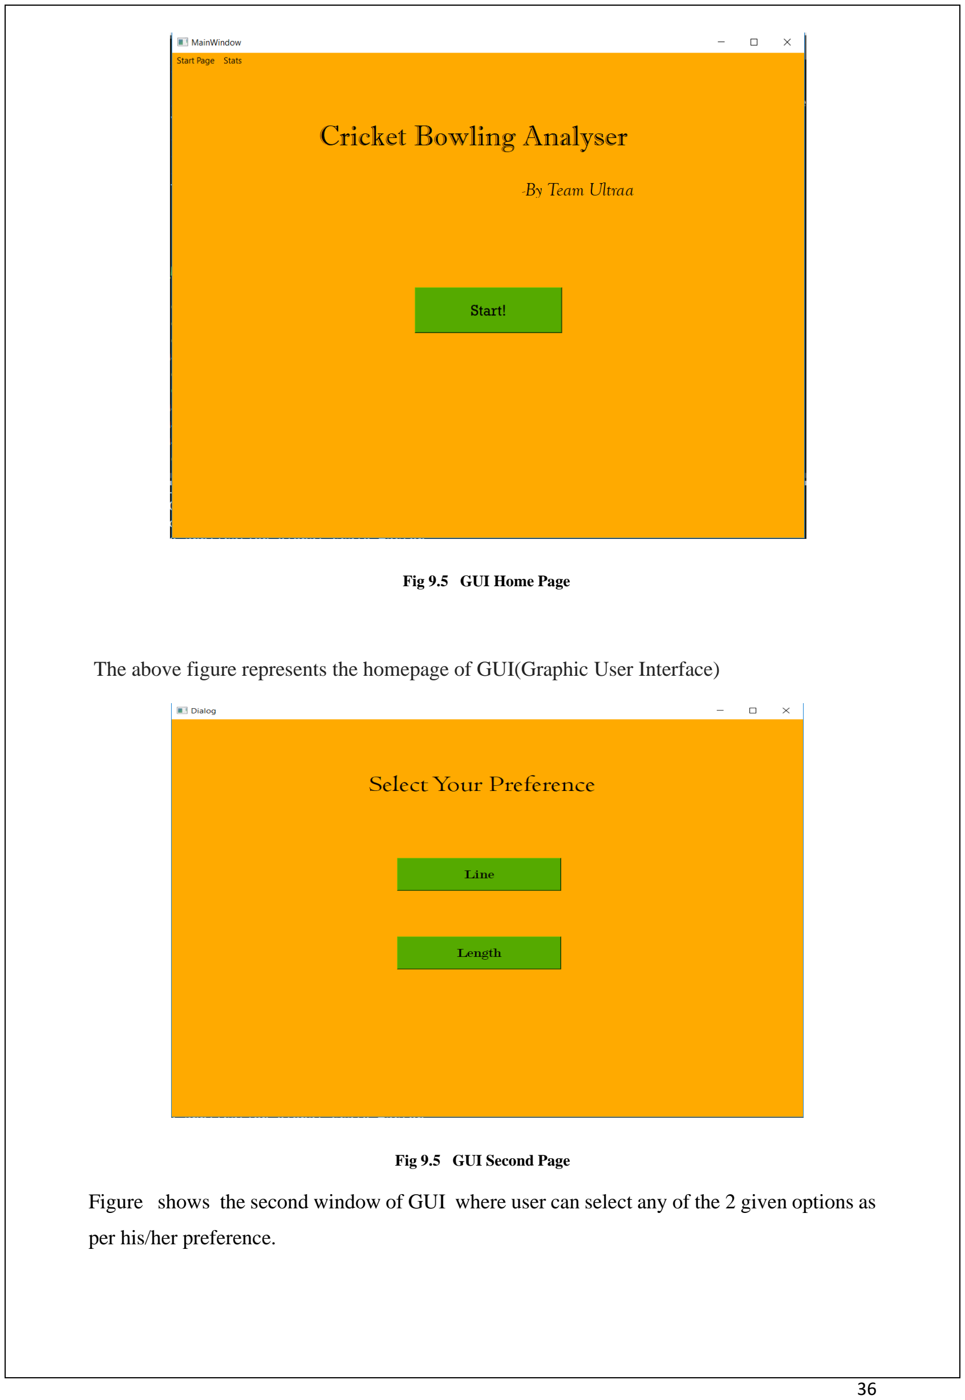
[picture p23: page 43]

Fig 9.4 GUI Home page

Fig 9.5 GUI Home Page

The above figure represents the homepage of GUI(Graphic User Interface)

Fig 9.5 GUI Second Page

Figure shows the second window of GUI where user can select any of the 2 given options as

per his/her preference.

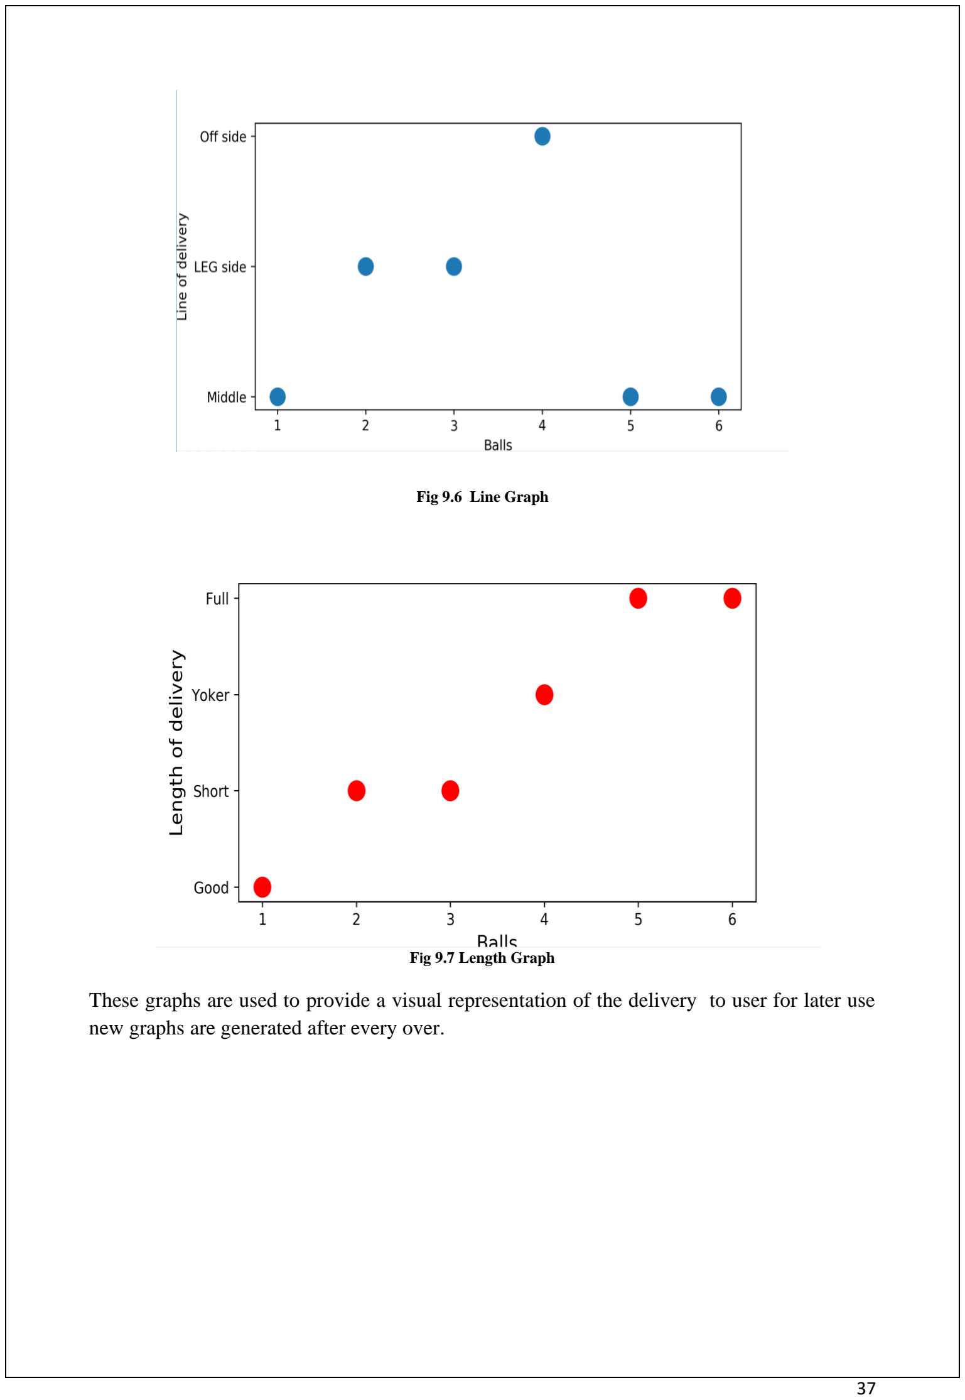
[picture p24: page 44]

Fig 9.6 Line Graph

Fig 9.7 Length Graph

These graphs are used to provide a visual representation of the delivery to user for later use new graphs are generated after every over.

## CHAPTER 10

## 10. Conclusion and Future Scope

## 10.1 Conclusion:

The proposed system Cricket Bowling is a low-cost alternative that can help in

monitoring of bowling system which can effectively calculate the basic 3 parameters of the

cricket coaching system. Self-fabricated Sensors are used to detect the delivery balls.

Furthermore, the user can monitor the individual balls continuously and the status of ball’s

location is updated in real time. Therefore, this proposed system can overcome the traditional

method of single coach system. At the same time, it offers cost savings and reliability which

convince the users all time. The advantages consist of personalized cricket coaching system

and tracking.

## 10.2 Future Scope:

- This system can further be improved by upgrading the speed measurement equipment,

which currently works on the not so reliable ultrasonic sensor.

- The speed can be measured using a more reliable radar based system using the concept

of doppler shift.

- Additional equipment can be utilized to provide a 3D trajectory of the delivery.

## CHAPTER 11

## References

WEBSITE:
[1]Pitch Vision: https://www.pitchvision.com/category/cricket#/

[2]Honeywell: https://sensing.honeywell.com/sensors/force-sensors (Force sensor)

[3]Piezoelectric: https://www.efxkits.us/piezoelectric-sensor-interfacing-arduino/

[4]Pressure mat: https://blog.hackster.io/yoga-mat-size-pressure-sensor-matrix-uses-

lattepanda-and-velostat-to-save-money-49ee86950e5a

[5]Processing3: https://processing.org/reference/

[6]Python: https://www.python.org/doc/

[7]Arduino: https://www.arduino.cc/reference/en/

[8]Adafruit: https://www.adafruit.com/?q=velostat

IEEE PAPERS:

[1] Suprapto, Sena & Setiawan, A.W. & Zakaria, H & Adiprawita, W & Supartono, B.

(2017). Low-Cost Pressure Sensor Matrix Using Velostat. 137-140. 10.1109/ICICI-

BME.2017.8537720.

## ANNEXURE

## Arduino Code

const byte s0 = 26;//selection pins for bigmat columns (O/p section) const byte s1 = 27;// EF
const byte s2 = 28;//port A
const byte s3 = 29;

const byte bc0 = 45;//o/p section for small mat const byte bc1 = 44;//port L
const byte bc2 = 43;
const byte bc3 = 42;

const byte t0 = 53;//big mat i/p section 1 const byte t1 = 52;// port b
const byte t2 = 51;//ip1
const byte t3 = 50;

const byte br0 = 33;//small mat ip section const byte br1 = 32;
const byte br2 = 31;
const byte br3 = 30;//port C

int mu = 0;
int t = 0;
int star = 0;
float ttemp = 0;
//op variables
int a = 0;
int b = 0;
int c = 0;
int d = 0;
int ca=0,cb=0,cc=0,cd=0;

//mat ''op analog " pin default for arduino mega #define SIG_pin A7
#define SIG_pin2 A2

// input to mux" pin default for arduino mini pro const byte OUT_pin1 = 7;//ip pins for big mat 1 const byte OUT_pin3=9;//small mat i/p

byte
p3[16]={B00000000,B00010000,B00100000,B00110000,B01000000,B01010000,B01100000,B01110000,B10 000000,B10010000,B10100000,B10110000,B11000000,B11010000,B11100000,B11110000};
byte
p2[16]={B00000000,B00000001,B00000010,B00000011,B00000100,B00000101,B00000110,B00000111,B00 001000,B00001001,B00001010,B00001011,B00001100,B00001101,B00001110,B00001111};

int valor = 0;//variable for sending bytes to processing int valorback=0;
int tt2=0;
//matrix for mat
int calibra[15][12]; //big
int calibra_b[12][9];//back
int maxsensor[15][12];//Calibration array for the min values of each od the 225 sensors. int maxsensor_b[12][9];
int minsensor_b=1000;
int temp=0;
int temp2=0;
int rw=0;
int cl=0;
int ttemp2=0;
int star2=0; //Variable for staring the min array void setup()
{
pinMode(s0, OUTPUT);
pinMode(s1, OUTPUT);
pinMode(s2, OUTPUT);
pinMode(s3, OUTPUT);

pinMode(t0, OUTPUT);
pinMode(t1, OUTPUT);
pinMode(t2, OUTPUT);
pinMode(t3, OUTPUT);

pinMode(bc0, OUTPUT);
pinMode(bc1, OUTPUT);
pinMode(bc2, OUTPUT);
pinMode(bc3, OUTPUT);

pinMode(br0, OUTPUT);
pinMode(br1, OUTPUT);
pinMode(br2, OUTPUT);
pinMode(br3, OUTPUT);

pinMode(OUT_pin1, OUTPUT); pinMode(OUT_pin3, OUTPUT);

digitalWrite(s0, LOW);
digitalWrite(s1, LOW);
digitalWrite(s2, LOW);
digitalWrite(s3, LOW);

digitalWrite(t0, LOW);
digitalWrite(t1, LOW);
digitalWrite(t2, LOW);
digitalWrite(t3, LOW);

digitalWrite(bc0, LOW);

digitalWrite(bc1, LOW);
digitalWrite(bc2, LOW);
digitalWrite(bc3, LOW);

digitalWrite(br0, LOW);
digitalWrite(br1, LOW);
digitalWrite(br2, LOW);
digitalWrite(br3, LOW);

digitalWrite(OUT_pin1, HIGH); digitalWrite(OUT_pin3, HIGH);

Serial.begin(115200);
sbi(ADCSRA, ADPS2);
cbi(ADCSRA, ADPS1);
cbi(ADCSRA, ADPS0);

// Full of 0's of initial matrix for(byte j = 0; j < 15; j ++) {

for(byte i = 0; i < 12; i ++) {calibra[j][i] = 0;
maxsensor[j][i]=0; }}

backscreendefine();

for(byte k = 0; k < 50; k++){ for(byte j = 0; j < 15; j ++){

writeMux1(j);
for(byte i = 0; i < 12; i ++)
{ temp=readMux(i);
calibra[j][i] = calibra[j][i]+temp; if( temp>maxsensor[j][i])
{maxsensor[j][i]=temp; }}}}

for(byte j = 0; j < 15; j ++) {

writeMux1(j);
for(byte i = 0; i < 12; i ++){ calibra[j][i] = calibra[j][i]/50; }}

backscreen_calib();

}
void loop() {

sensing(); }

int readMux(byte channel){ PORTA=p3[channel];
int val = analogRead(SIG_pin);

//return the value
return val; }

int readMux2(byte channel){ PORTL=p3[channel];
int val = analogRead(SIG_pin2);

//return the value
return val; }

void writeMux1(byte channel){ PORTB=p2[channel]; }

void writeMux3(byte channel){ PORTC=p3[channel]; }

void backscreendefine() {

for(byte p = 0; p < 12; p ++) {

for(byte q = 0; q < 9; q ++) {

calibra_b[p][q] = 0;
maxsensor_b[p][q]=0; }}}

void backscreen_calib() {

for(byte k = 0; k < 70; k++){ for(byte p = 0; p < 12; p ++){ writeMux3(p);
for(byte q = 0; q < 9; q ++){ temp2=readMux2(q);
calibra_b[p][q] = calibra_b[p][q]+temp2;

if( temp2>maxsensor_b[p][q]) {maxsensor_b[p][q]=temp2;
}}}}

for(byte j = 0; j < 12; j ++){ writeMux3(j);
for(byte i = 0; i < 9; i ++){ calibra_b[j][i] = calibra_b[j][i]/70; }}}

## Speed:

#define trigPin 9

#define echoPin 10

float duration,distancem1,distancem2,speed0,distm,sum=0,i=0;

void setup() {
Serial.begin(9600);
pinMode(trigPin, OUTPUT);
pinMode(echoPin, INPUT);
pinMode(13,OUTPUT);
pinMode(7,OUTPUT);

}
void loop() {
digitalWrite(trigPin, LOW); delayMicroseconds(2);
digitalWrite(trigPin, HIGH); delayMicroseconds(10);
digitalWrite(trigPin, LOW); duration = pulseIn(echoPin, HIGH); distancem1= duration*0.034/200; //Serial.println(distancem1); delay(150);
digitalWrite(trigPin, LOW); delayMicroseconds(2);
digitalWrite(trigPin, HIGH); delayMicroseconds(10);
digitalWrite(trigPin, LOW); duration = pulseIn(echoPin, HIGH); distancem2= duration*0.034/200; distm=distancem1-distancem2; speed0=distm/0.15;
speed0=speed0*3.6;
if (distancem1<=300) {
if(distancem1>distancem2){ sum=sum+speed0;
i=i+1;
}}
if(i==2)
{
if(sum>0){
Serial.print("Speed of delivery is") ; Serial.print(sum/2);
Serial.println();

i=0;
sum=0;
}
}

## Processing3 Code

import processing.serial.*;
Serial myPort; //the Serial port object String val;
int[] input = new int [4];
//int[] inputr = new int [2];
int serialCount=0;
int tiempoant;
boolean firstContact = false; String sensorReading="";
import java.io.BufferedWriter; import java.io.FileWriter;
String outFilename = "data.csv";
void setup() {
size(960, 960,P3D); //make our canvas 200 x 200 pixels big

myPort = new Serial(this, Serial.list()[0], 115200); appendTextToFile(outFilename,"Date,Time,Length_x,Length_y,Line_x,Line_y\n"); }
void draw() {
textSize(30);

fill(0,0,255);

translate(800,800);
rotateX(radians(60));
background(0);

for (int j=0; j<15; j++) { for (int i=0; i<12; i++) { stroke(255);
if (j>=12 && j<=15){
fill(255,255,51);
rect(-60*i,-120*j,60,120); }
else if(j>=6 && j<12){
fill(0,255,0);
rect(-60*i,-120*j,60,120); }
else if(j>=3 && j<6){
fill(255,0,0);
rect(-60*i,-120*j,60,120); }
else if(j<3){
fill(100,149,237);
rect(-60*i,-120*j,60,120); }
}

}

int a=input[1];
int b=input[0];
fill(0,0,0);
rect(-60*a,-120*b,60,120); pushMatrix();
translate(-242,0,535);
rotateX(radians(-60));
scale(0.52);
for (int i=0; i<12; i++) { for (int j=0; j<12; j++) { stroke(255);
if (i>=8 && i<=11){
fill(255,128,0);
rect(-i*28,-j*28,28,28);
}
else if(i>=4 && i<8){
fill(128,128,128);
rect(-i*28,-j*28,28,28);
if(i>=5 && i<=6 && j<4)
{
fill(204,204,0);
rect(-i*28,-j*28,28,28);
}
}
else if(i>=0 && i<4){
fill(153,0,73);
rect(-i*28,-j*28,28,28);
}
}
}
int c=11-input[3];
int d=11-input[2];
fill(0,0,0);
rect(-28*c,-28*d,28,28);
fill(255,255,51);
text("Yorker", 40,60);
fill(0,255,0);
text("Full", 125, 200);
fill(255,0,0);
text("Good", 215, 400);
fill(100,149,237);
text("Short", 330, 650);
tint(255, 200);
//image(img, -700, -475);

popMatrix();
}
void serialEvent(Serial myPort) {sensorReading = myPort.readStringUntil('\n'); if(sensorReading != null){
int d=day();
int m=month();
int y=year();

String dmy=str(d)+"-"+str(m)+"-"+str(y); int h=hour();
int mi=minute();
int sec=second();
String time=str(h)+":"+str(mi)+":"+str(sec); sensorReading=trim(sensorReading);
int abc[] = int(split(sensorReading, ',')); appendTextToFile(outFilename,dmy+","+time+","+sensorReading); input[0]=abc[0];
input[1]=abc[1];
input[2]=abc[2];
input[3]=abc[3];
println(abc);

void appendTextToFile(String filename, String text){ File f = new File(dataPath(filename)); if(!f.exists()){
createFile(f);
}
try {
PrintWriter out = new PrintWriter(new BufferedWriter(new FileWriter(f, true))); // true to append the output out.println(text);
out.close(); | // clean close allows to read / copy file while processing runs
}catch (IOException e){
e.printStackTrace();
}
}
void createFile(File f){
File parentDir = f.getParentFile(); try{
parentDir.mkdirs();
f.createNewFile();
}
catch(Exception e){
e.printStackTrace();
}
}

## GUI Code in Python3

import sys
from PyQt5 import QtCore, QtGui, QtWidgets
from PyQt5.QtWidgets import QDialog, QApplication, QPushButton, QVBoxLayout, QLabel, QWidget import csv
from PyQt5.QtGui import QPixmap
from matplotlib.backends.backend_qt5agg import FigureCanvasQTAgg as FigureCanvas
from matplotlib.backends.backend_qt5agg import NavigationToolbar2QT as NavigationToolbar import matplotlib.pyplot as plt

class Ui_MainWindow(object):
def abc(self):
self.window = QtWidgets.QMainWindow() self.ui = Ui_Dialog()
self.ui.setupUi1(self.window) MainWindow.hide()
self.window.show()
def setupUi(self, MainWindow): MainWindow.setObjectName("MainWindow") MainWindow.resize(1120, 860) MainWindow.setStyleSheet("background-color: rgb(255, 170, 0);") self.centralwidget = QtWidgets.QWidget(MainWindow) self.centralwidget.setObjectName("centralwidget")
self.label = QtWidgets.QLabel(self.centralwidget) self.label.setGeometry(QtCore.QRect(260, 90, 551, 61)) font = QtGui.QFont()
font.setFamily("Imprint MT Shadow") font.setPointSize(30)
self.label.setFont(font)
self.label.setObjectName("label")
self.label_2 = QtWidgets.QLabel(self.centralwidget) self.label_2.setGeometry(QtCore.QRect(620, 200, 211, 31)) font = QtGui.QFont()
font.setFamily("Goudy Old Style")
font.setPointSize(20)
font.setItalic(True)
self.label_2.setFont(font)
self.label_2.setObjectName("label_2")
self.pushButton = QtWidgets.QPushButton(self.centralwidget) self.pushButton.setGeometry(QtCore.QRect(430, 390, 261, 81)) font = QtGui.QFont()
font.setFamily("Rockwell")
font.setPointSize(16)
self.pushButton.setFont(font) self.pushButton.setMouseTracking(True) self.pushButton.setAutoFillBackground(False) self.pushButton.setStyleSheet("background-color: rgb(85, 170, 0);") self.pushButton.setObjectName("pushButton")

self.pushButton.clicked.connect(self.abc)

MainWindow.setCentralWidget(self.centralwidget) self.menubar = QtWidgets.QMenuBar(MainWindow) self.menubar.setGeometry(QtCore.QRect(0, 0, 1124, 26)) self.menubar.setObjectName("menubar") self.menuStart_Page = QtWidgets.QMenu(self.menubar) self.menuStart_Page.setObjectName("menuStart_Page") self.menuStats = QtWidgets.QMenu(self.menubar) self.menuStats.setObjectName("menuStats") MainWindow.setMenuBar(self.menubar) self.statusbar = QtWidgets.QStatusBar(MainWindow) self.statusbar.setObjectName("statusbar") MainWindow.setStatusBar(self.statusbar) self.actionLine = QtWidgets.QAction(MainWindow) self.actionLine.setObjectName("actionLine") self.actionLength = QtWidgets.QAction(MainWindow) self.actionLength.setObjectName("actionLength") self.menuStats.addAction(self.actionLine) self.menuStats.addAction(self.actionLength) self.menubar.addAction(self.menuStart_Page.menuAction()) self.menubar.addAction(self.menuStats.menuAction())

self.retranslateUi(MainWindow) QtCore.QMetaObject.connectSlotsByName(MainWindow)

def retranslateUi(self, MainWindow):
_translate = QtCore.QCoreApplication.translate MainWindow.setWindowTitle(_translate("MainWindow", "MainWindow")) self.label.setText(_translate("MainWindow", "Cricket Bowling Analyser")) self.label_2.setText(_translate("MainWindow", "-By Team Ultraa")) self.pushButton.setText(_translate("MainWindow", "Start!")) self.menuStart_Page.setTitle(_translate("MainWindow", "Start Page")) self.menuStats.setTitle(_translate("MainWindow", "Stats")) self.actionLine.setText(_translate("MainWindow", "Line")) self.actionLength.setText(_translate("MainWindow", "Length"))

##Stats page##

class Ui_Dialog(object):
def abd(self):
lst_leng=[]
with open("people.csv", 'r') as csvfile: reader = csv.DictReader(csvfile)
for row in reader:
data=dict(row)
lst_leng.append([data['lengthx'],data['lengthy']])

csvfile.close()
print(lst_leng)

length=[]
for lst in lst_leng:
lst=int(lst[0])

if(lst<=2):
length.append('Yoker')
elif(lst<=6):
length.append('Full')
elif(lst<=10):
length.append('Good')
else:
length.append('Short')
print(length)

over=list(range(1,7))
print(over)
plt.figure(1, figsize=(18,18), dpi=250) plt.scatter(over,length,s=150,c='r') plt.xlabel("Balls",fontsize=13) plt.ylabel('Length of delivery',fontsize=13) plt.savefig('test1.jpg')

plt.show()
print(5)
# self.window = QtWidgets.QDialog() # self.ui = Ui_Dialoge()

# self.ui.setupUi2(self.window)

# Dialog.hide()

# self.window.show()

def abline(self):

lst_line=[]
with open("people.csv", 'r') as csvfile: reader = csv.DictReader(csvfile) for row in reader:
data=dict(row)

lst_line.append([data['linex'],data['liney']]) csvfile.close()

line=[]

for lst in lst_line:
lst=int(lst[1])
if(lst<=3):
line.append('Off side')
elif(lst<=6):
line.append('Middle')
else:
line.append('LEG side')
print(line)
over=list(range(1,7))
print(over)

plt.figure(2, figsize=(18, 18), dpi=250)

plt.scatter(over,line,s=150) plt.xlabel("Balls")
plt.ylabel('Line of delivery') plt.savefig('test2.jpg')
plt.show()
print(5)
#def abx(self):

# self.window = QtWidgets.QDialog() # self.ui = Ui_Dialoge()

# self.ui.setupUi2(self.window)

# Dialog.hide()

# self.window.show()

def setupUi1(self, Dialog):
Dialog.setObjectName("Dialog")
Dialog.resize(1120, 860)
Dialog.setStyleSheet("background-color: rgb(255, 170, 0);") self.label = QtWidgets.QLabel(Dialog) self.label.setGeometry(QtCore.QRect(350, 90, 411, 101)) font = QtGui.QFont()
font.setFamily("Centaur")
font.setPointSize(30)
self.label.setFont(font)
self.label.setObjectName("label")
self.pushButton = QtWidgets.QPushButton(Dialog) self.pushButton.setGeometry(QtCore.QRect(400, 300, 291, 71)) font = QtGui.QFont()
font.setFamily("Modern No. 20")
font.setPointSize(16)
self.pushButton.setFont(font) self.pushButton.setStyleSheet("background-color: rgb(85, 170, 0);") self.pushButton.setObjectName("pushButton")
self.pushButton_2 = QtWidgets.QPushButton(Dialog) self.pushButton_2.setGeometry(QtCore.QRect(400, 470, 291, 71)) font = QtGui.QFont()
font.setFamily("Modern No. 20")
font.setPointSize(16)
self.pushButton_2.setFont(font) self.pushButton_2.setStyleSheet("background-color: rgb(85, 170, 0);") self.pushButton_2.setObjectName("pushButton_2")

self.pushButton.clicked.connect(self.abline) self.pushButton_2.clicked.connect(self.abd)

self.retranslateUi1(Dialog) QtCore.QMetaObject.connectSlotsByName(Dialog)

def retranslateUi1(self, Dialog):
_translate = QtCore.QCoreApplication.translate Dialog.setWindowTitle(_translate("Dialog", "Dialog")) self.label.setText(_translate("Dialog", "Select Your Preference")) self.pushButton.setText(_translate("Dialog", "Line")) self.pushButton_2.setText(_translate("Dialog", "Length"))

##graph page##

class Ui_Dialoge(object):
def abe(self):
self.window = QtWidgets.QMainWindow() self.ui = Ui_Dialog()
self.ui.setupUi1(self.window) Dialoge.hide()
self.window.show()
def setupUi2(self, Dialoge):
Dialoge.setObjectName("Dialoge")
Dialoge.resize(1120, 860)
Dialoge.setStyleSheet("background-color: rgb(255, 170, 0);") self.pushButton = QtWidgets.QPushButton(Dialoge) self.pushButton.setGeometry(QtCore.QRect(490, 810, 93, 28)) self.pushButton.setStyleSheet("background-color: rgb(85, 170, 0);") self.pushButton.setObjectName("pushButton")

self.pushButton.clicked.connect(self.abe self.retranslateUi2(Dialoge) QtCore.QMetaObject.connectSlotsByName(Dialoge) def retranslateUi2(self, Dialoge):
_translate = QtCore.QCoreApplication.translate Dialoge.setWindowTitle(_translate("Dialoge", "Dialoge")) self.pushButton.setText(_translate("Dialoge", "BACK")) #image#
if __name__ == "__main__":
import sys
app = QtWidgets.QApplication(sys.argv) MainWindow = QtWidgets.QMainWindow() Dialog = QtWidgets.QMainWindow() Dialoge = QtWidgets.QMainWindow()
ui = Ui_MainWindow()
ui.setupUi(MainWindow)
MainWindow.show()
sys.exit(app.exec_()

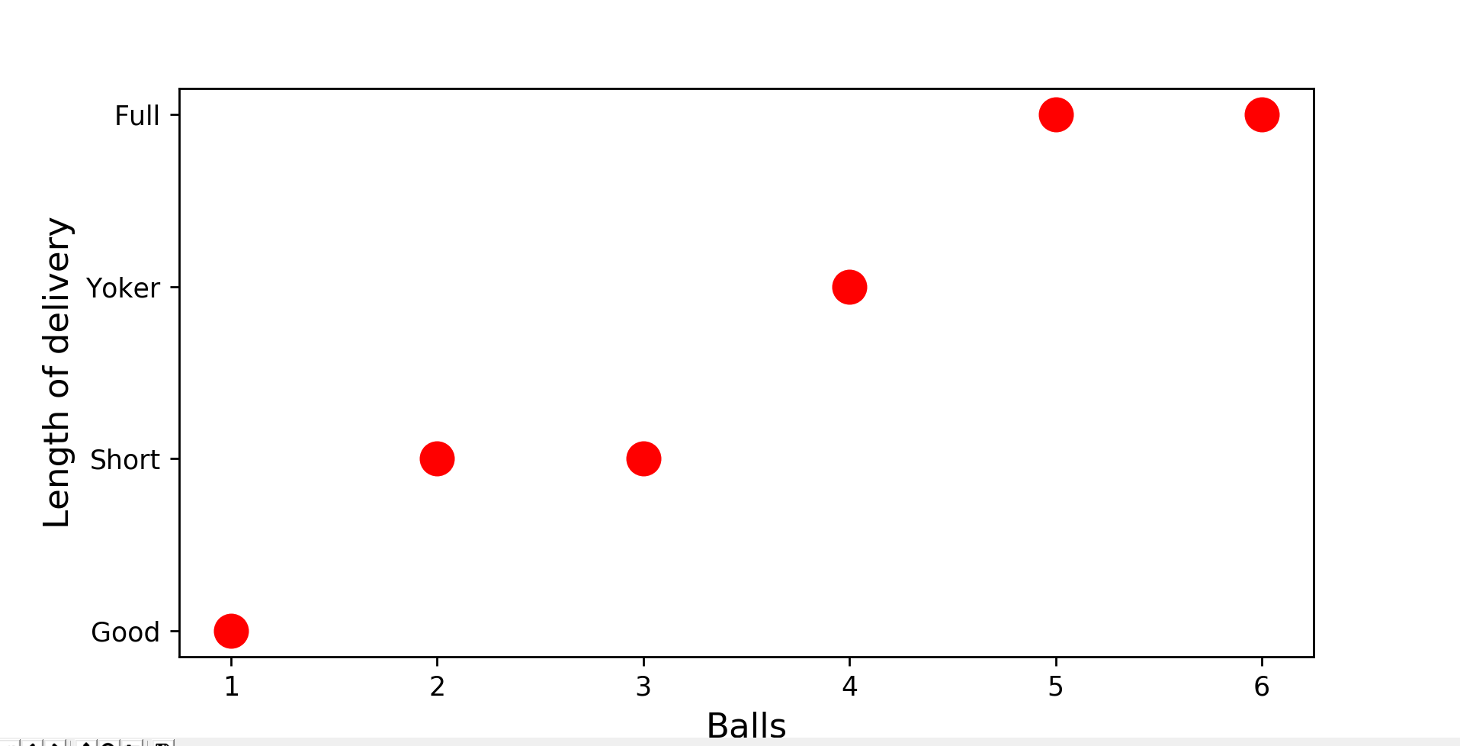
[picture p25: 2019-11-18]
GUI/Capture.PNG

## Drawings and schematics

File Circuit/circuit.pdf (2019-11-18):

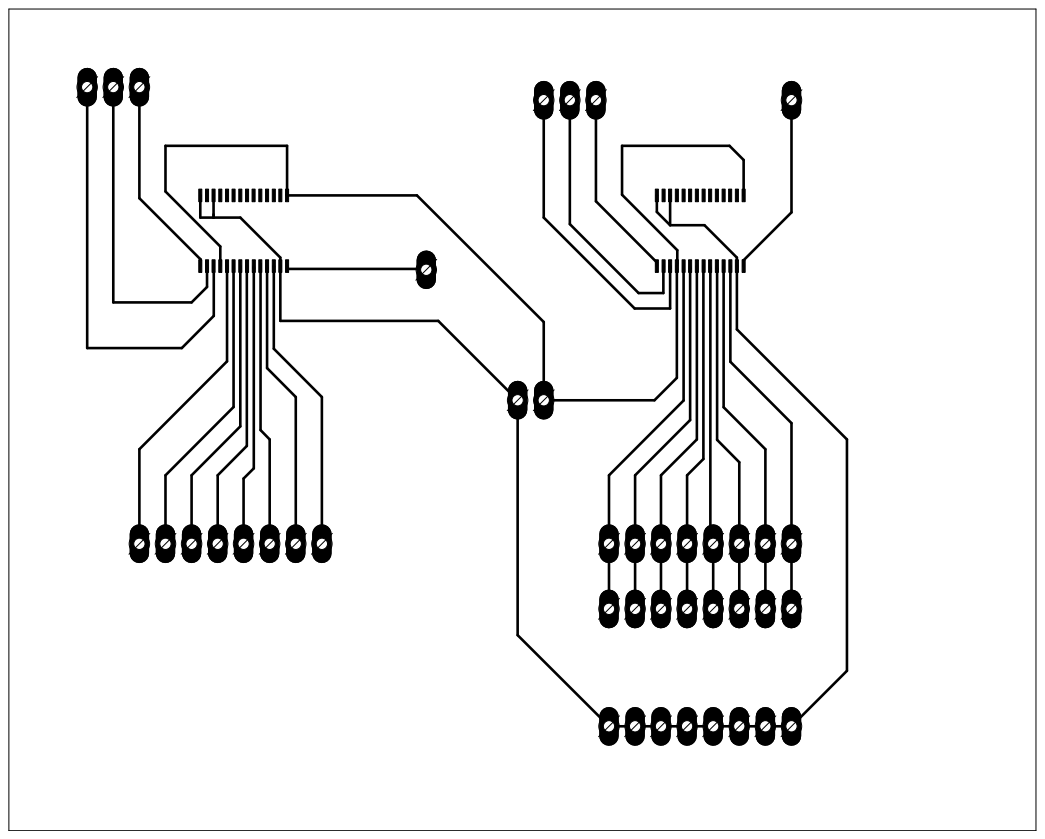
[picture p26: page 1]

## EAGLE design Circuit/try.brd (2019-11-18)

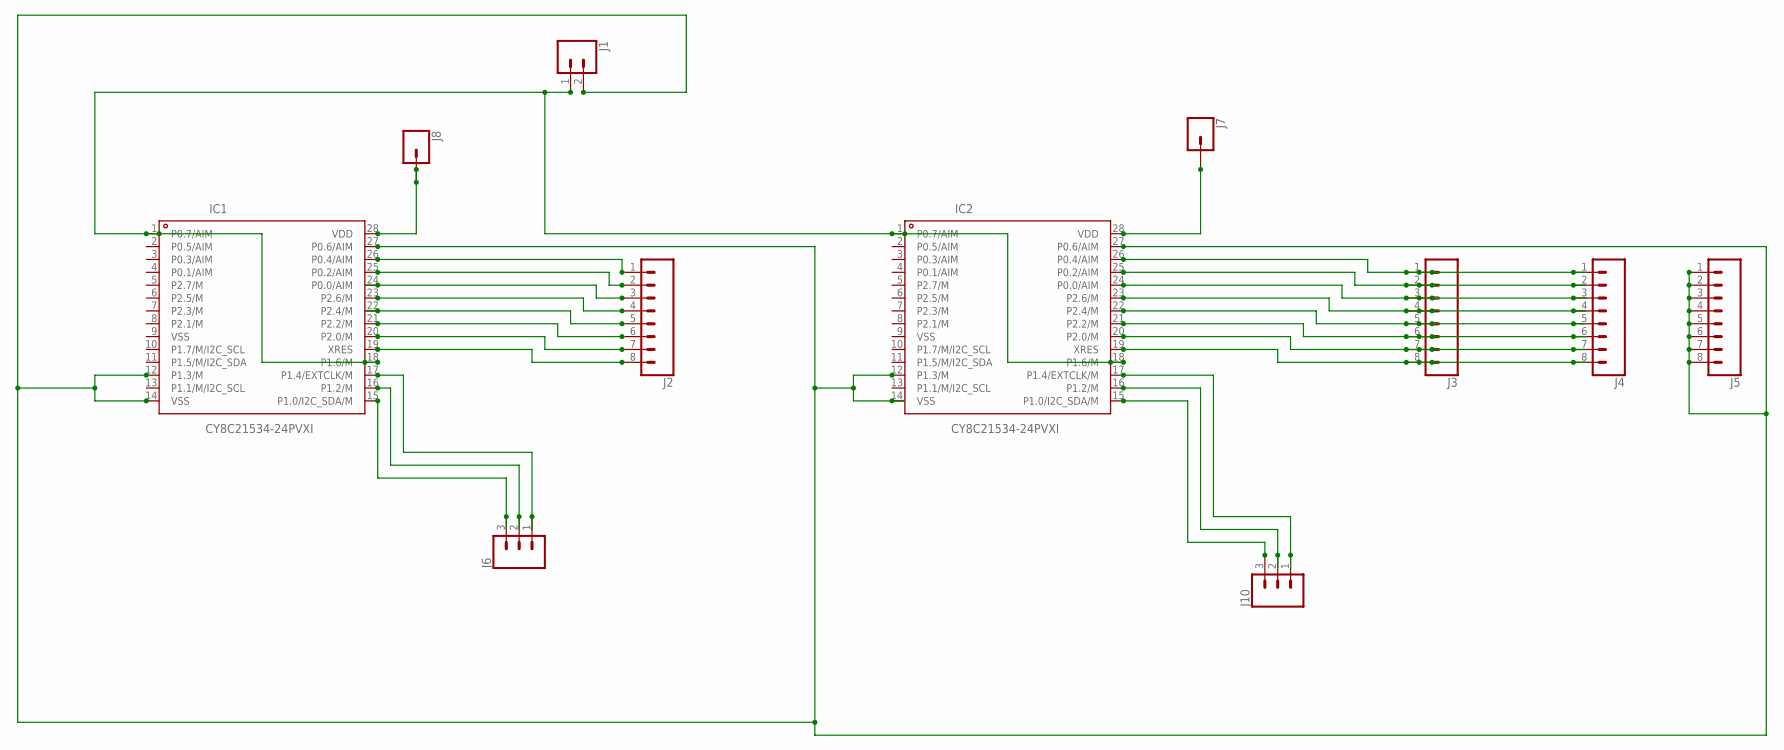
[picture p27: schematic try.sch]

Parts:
IC1, IC2: CY8C21534-24PVXI; SSOP28
J1: CONN_02PTH3; 1X02_LONGPADS
J2, J3, J4, J5: CONN_08LONGPADS; 1X08_LONGPADS
J6, J10: CONN_03LONGPADS; 1X03_LONGPADS
J7, J8: CONN_01PTH_LONGPAD; 1X01_LONGPAD

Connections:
unnamed: IC1.17 (P1.4/EXTCLK/M), J6.1
unnamed: IC2.15 (P1.0/I2C_SDA/M), J10.3
unnamed: IC1.12 (P1.3/M), IC1.14 (VSS), IC1.27 (P0.6/AIM), IC2.12 (P1.3/M), IC2.14 (VSS), IC2.27 (P0.6/AIM), J1.2, J5.1, J5.2, J5.3, J5.4, J5.5, J5.6, J5.7, J5.8
unnamed: IC1.26 (P0.4/AIM), J2.1
unnamed: IC1.25 (P0.2/AIM), J2.2
unnamed: IC1.24 (P0.0/AIM), J2.3
unnamed: IC1.23 (P2.6/M), J2.4
unnamed: IC1.22 (P2.4/M), J2.5
unnamed: IC1.21 (P2.2/M), J2.6
unnamed: IC1.20 (P2.0/M), J2.7
unnamed: IC1.19 (XRES), J2.8
unnamed: IC2.26 (P0.4/AIM), J3.1, J4.1
unnamed: IC2.25 (P0.2/AIM), J3.2, J4.2
unnamed: IC2.24 (P0.0/AIM), J3.3, J4.3
unnamed: IC2.23 (P2.6/M), J3.4, J4.4
unnamed: IC2.22 (P2.4/M), J3.5, J4.5
unnamed: IC2.21 (P2.2/M), J3.6, J4.6
unnamed: IC2.20 (P2.0/M), J3.7, J4.7
unnamed: IC2.19 (XRES), J3.8, J4.8
unnamed: IC1.1 (P0.7/AIM), IC1.18 (P1.6/M), IC2.1 (P0.7/AIM), IC2.18 (P1.6/M), J1.1
unnamed: IC1.28 (VDD), J8.1
unnamed: IC2.28 (VDD), J7.1
unnamed: IC1.15 (P1.0/I2C_SDA/M), J6.3
unnamed: IC1.16 (P1.2/M), J6.2
unnamed: IC2.16 (P1.2/M), J10.2
unnamed: IC2.17 (P1.4/EXTCLK/M), J10.1

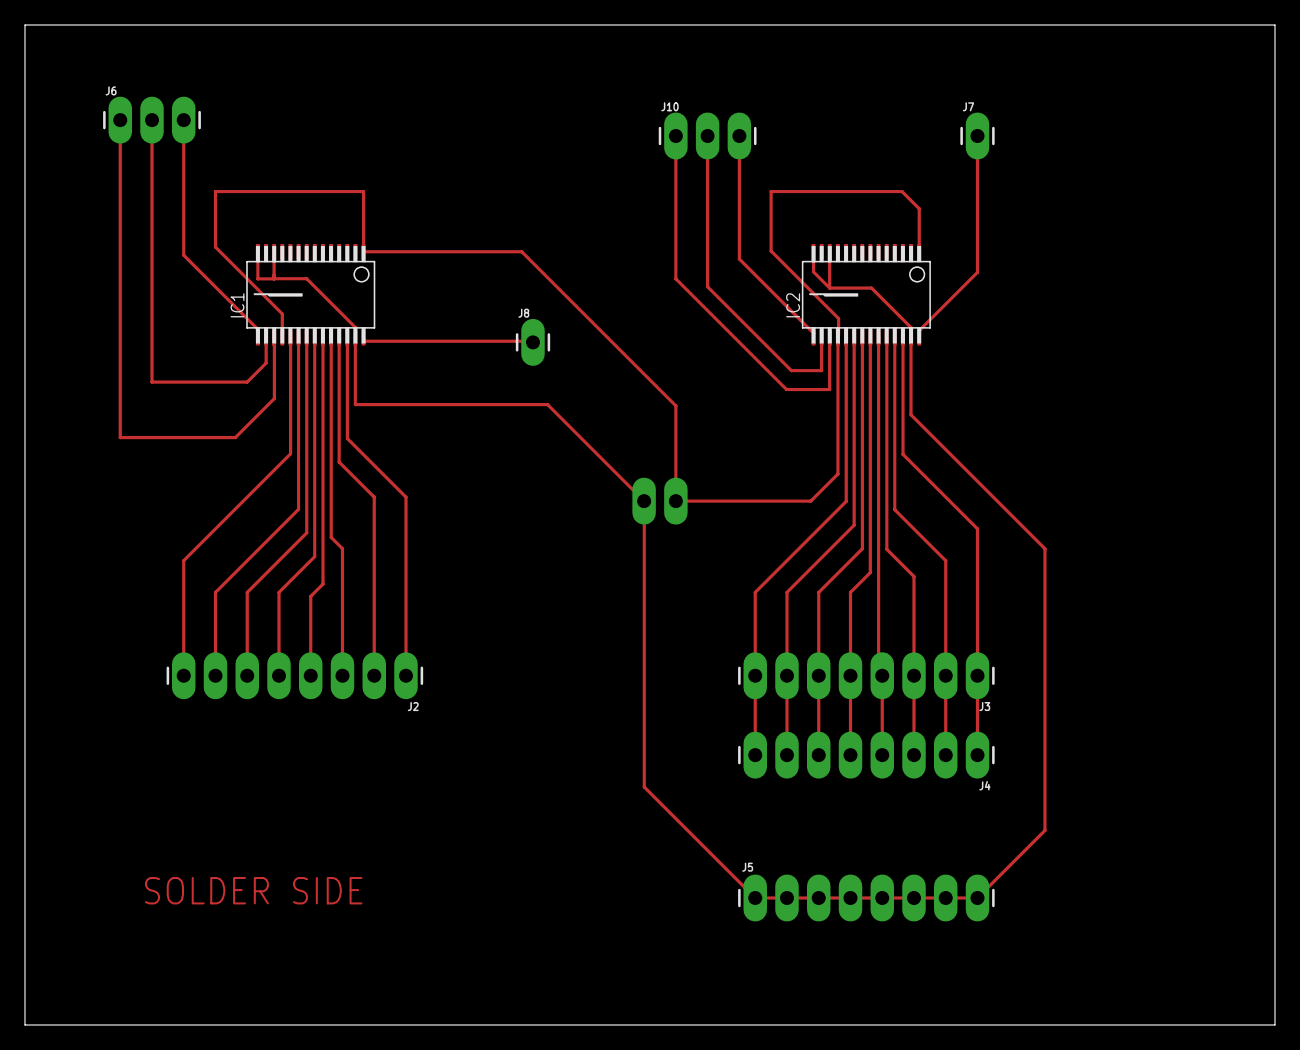
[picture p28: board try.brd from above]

Board: 2 copper layers, 100.0 x 80.0 mm, 11 parts (1 on the bottom side), 26 nets.

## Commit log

2019-11-18 arduino file of data acquisiton from sensor matrix
2019-11-18 Arduino code for speed measurment
2019-11-18 Code for user interface
    [people.csv]
2019-11-18 Circuit pcb schematic
    [try.brd, try.sch]

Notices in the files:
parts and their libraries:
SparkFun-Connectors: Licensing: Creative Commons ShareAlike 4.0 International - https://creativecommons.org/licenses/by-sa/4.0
